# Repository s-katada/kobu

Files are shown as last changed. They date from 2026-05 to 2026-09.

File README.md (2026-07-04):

# kobu

自作分割キーボード「kobu」のモノレポです。世代ごとにディレクトリを分けています。

## ディレクトリ構成

| ディレクトリ | 中身 |
|---|---|
| [`v1/`](v1/) | 初代 kobu — KiCad PCB / ケース / ファームウェア (RMK・ZMK) / Web キーマップエディタ。詳細は [`v1/README.md`](v1/README.md) |
| [`v2/`](v2/) | kobu v2 — ケース / RMK ファームウェア。小指キーを左右 1 個ずつ追加した第 2 世代 (kobu2, PID 0x425A)。詳細は [`v2/README.md`](v2/README.md) |

## 開発環境

Nix flake / direnv。ルートの [`flake.nix`](flake.nix) が toolchain バージョンの単一情報源で、CI も同じ devshell で走ります。使い方は [`v1/README.md`](v1/README.md#開発環境) を参照。

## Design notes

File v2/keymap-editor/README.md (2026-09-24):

# kobu2 keymap editor

kobu2（v2）のキーマップとトラックボール設定を、ブラウザから直接編集する SPA です。
実機の見た目そのままの盤面を出し、**変えたいキーをクリックして選ぶ**だけで割り当てを
変更できます。

- 公開先: `https://kobu-editor.digletts.dev/v2/`（v1 と同じ Worker の `/v2` 配下）
- 対象: **kobu2 のみ**（USB PID `0x425A` / set 2 の `0x425B`）。初代 kobu はキー配列が違うので
  [`../../v1/web/rmk-editor`](../../v1/web/rmk-editor) を使ってください。
- 必要環境: WebHID が使えるデスクトップブラウザ（Chrome / Edge など Chromium 系）

kobu2 実機

## できること

| 機能 | 内容 |
|---|---|
| キーマップ編集 | 7 レイヤー × 40 キー。盤面のキーをクリック → 検索・カテゴリ・実キー入力から選択 |
| 動作の装飾 | 修飾つき (WM) / 長押しで修飾 (MT) / 長押しでレイヤー (LT) / レイヤー操作 (MO・TG・TO・OSL・DF) |
| チューニング | カーソル速度 (CPI 倍率)、スクロール間隔・反転、ステータス LED のしきい値。**その場で実機に反映** |
| バッテリー表示 | 左右それぞれの残量（30 秒ごとに自動更新） |
| 通電テスト | 全 40 キーを 1 つずつ押して、スイッチが MCU まで届いているか確かめます（組み立て後の導通確認） |
| デモ表示 | 実機が無くても盤面と操作感を確認できます |

キーマップの変更はいったん手元に溜まり、**「キーボードに書き込む」** で一括送信します。
ロック解除の操作は要りません — Vial の作法では書き込み前に解除しますが、rmk 0.8.2 が
ロックでゲートしているのは通電テストが読む `SwitchMatrixState` の 1 箇所だけで
（`host/via/mod.rs:140`、クレート中で `is_unlocked()` を参照している唯一の場所）、
`DynamicKeymapSetKeyCode` は素通りします。

### 通電テスト

「通電テスト」タブは、**キーマップを通す前のスイッチの状態**を実機から読み出します。押した
キーが緑になり、最後まで緑にならないキーはスイッチ・ソケット・FFC・XIAO のピンのどこかで
導通していません（キーマップの問題ではありません）。列や行がまとまって残った場合はその旨を
表示するので、当たりを付けてテスターを当てられます。

読んでいるのは Via の `GetKeyboardValue / SwitchMatrixState (0x02 / 0x03)` で、ファームウェア
側は `matrix_state`（rmk がキーマップ参照より前に更新するビットマップ）をそのまま返します。
つまり**レイヤーキーや割り当ての無いキーも反応します**。実装は `src/protocol/matrix.ts` と
`src/state/matrixTest.ts`。

知っておくべき挙動が 3 つあります。

* **開始時に一度ロック解除が必要です。** ファームウェアはロック中だとビットマップを書かず、
  「どのキーも押されていない」と区別の付かない返事（要求のエコー＝全ゼロ）を返します。そのため
  開始ボタンを押すと解除操作（左右いちばん外側の小指キー 2 つを同時押し）を求めます。解除状態は
  電源を入れ直すまで続きます。解除キーは左右に 1 つずつなので、**右半分の電源が入っていないと
  解除自体ができません**。
  ⚠ この 2 バイト目の極性は間違えても静かに壊れます（ロック中の 0 を「解除済み」と読むと、
  チョードを要求しないまま全ゼロを読み続け、「入力はできるのに 1 つも反応しない」画面になる）。
  `src/protocol/unlock.test.ts` がファーム側の実装と突き合わせて固定しています。
* **右半分は左半分と BLE でつながっている必要があります。** ビットマップはセントラル（左）
  にあり、右のキーはペリフェラルが転送したイベントで更新されます。右の電源スイッチが
  入っていないと、右のキーは 1 つも反応しません。
* **テスト中の打鍵はページ側で握り潰します**（Esc で終了）。ただしブラウザ自体のショート
  カット（⌘W など）は JavaScript からは止められません。

ファームウェアの変更は不要です。この機能が使う `vial_lock` は rmk の既定 feature で、
`v2/firmware/rmk/Cargo.toml` はそれを無効にしていないため、現行の UF2 がそのまま応答します。

## 開発

Node / pnpm はリポジトリルートの flake が固定しています。

```sh
cd v2/keymap-editor         # direnv がルートの devshell (Node + pnpm) を起動
pnpm install
pnpm dev                    # http://localhost:5173
pnpm test                   # vitest
pnpm lint                   # biome
pnpm typecheck
pnpm build                  # dist/
```

デプロイ用のビルドだけ `--base=/v2/` を付けます（`.github/workflows/web.yml` 参照）。
ローカルの `pnpm dev` / `pnpm build` は `/` のままです。

## 構成

| ディレクトリ | 中身 |
|---|---|
| `src/transport/` | WebHID による Vial パケット送受信。v1 エディタから流用（PID だけ kobu2 に限定） |
| `src/protocol/` | Via / Vial コマンド、ハンドシェイク、キーマップ、キーコード辞書、Custom Value。v1 から流用（`matrix.ts` だけ v2 で追加） |
| `src/board/` | **v2 固有**。実基板 CAD から起こしたジオメトリと、盤面 SVG |
| `src/state/` | zustand ストア（接続 / キーマップ / チューニング / 通電テスト） |
| `src/components/` | UI |

### 盤面ジオメトリについて

`src/board/geometry.ts` は**すべて実測値**で、目分量で描いた形は入っていません。

| 要素 | 出所 |
|---|---|
| スイッチ位置・回転 | `v2/pcb/left-main`, `v2/pcb/thumb-left` の KiCad |
| ケース外形（メイン / 親指） | `v2/case/{main,thumb}-top-plate.stl` を z=0.5 でスライス |
| トラックボール筐体・XIAO 蓋・ヒンジ | `v2/case/*.stl` の実寸 |
| キーキャップの大きさ | 実機写真（プレートの 14mm 開口を定規に実測） |

v2 の基板はスイッチが **B.Cu 側**にあるため、KiCad の標準表示は物理的な上面視と左右反転して
います（コード内に変換式を記載）。

ケース部品は**平行移動だけ**でこの座標系に乗り、しかも位置合わせは推定ではなく**証明済み**です。
印刷されたトッププレートをスライスするとスイッチごとに 14.00×14.00mm の開口が現れ、その中心
20 個すべてが KiCad のスイッチ中心と **0.00mm で一致**します。トラックボール筐体も整合しており、
中心は PMW3610 のパッドから 0.3mm しかずれません。

**唯一の推定値**がメインユニットと親指ユニットの相対位置です。両者は別 KiCad プロジェクトで
原点が無関係なため、ここだけ上の実機写真に合わせ込んでいます（誤差 2mm 程度）。
右半分は左半分の剛体鏡像として生成しています。

プレート外形にはネジ座の逃げ（縁に食い込んだ浅い円弧）が入っていますが、組み上げた状態では
その外側をサイドプレートが通るため見えません。そこで**円弧状の小さな凹みだけ**を埋めています
（4 セグメント以上・9mm 未満・18mm² 未満）。実際の段差は 2〜3 本の直線なので、大きさではなく
形で区別され、列スタッガーは残ります。

この位置合わせが将来ずれないよう、3 つのテストで固定してあります。①全キーがキャップ四隅まで
プレート多角形の内側にあること ②メインプレートが最外キャップから四辺すべて 3.15mm の余白を
持つこと（1mm ずれると余白が揃わなくなる） ③親指プレートの後端が最外キーの中心から
12.65mm 後ろにあること。

### チューニング値の永続性

チューニングの各項目は Via Custom Channel `0xC0` 経由でファームの atomic を直接書き換えます。
**ファームは保存しないため、電源を入れ直すと既定値に戻ります**
（`v2/firmware/rmk/src/config.rs` の "Persistence" を参照）。恒久的に変えたい場合は
`keyboard.toml` を編集して焼き直してください。

また 7 項目のうち「縦スクロール反転」と「LED 紫の保持時間」は、現在のファームに読み取り側が
無いため動作に影響しません。UI 上でも無効表示にしてあります。

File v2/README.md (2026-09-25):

# kobu v2

自作分割キーボード kobu の第 2 世代。v1 との**ハード面の違いは小指列最下段のキーを左右 1 個ずつ追加**したことだけです（19 → 20 キー/半分、計 40 キー）。

初代の PCB / ケース / ファームウェア / Web エディタは [`../v1/`](../v1/) にあります。

## ディレクトリ構成

| ディレクトリ | 中身 |
|---|---|
| [`case/`](case/) | ケースの STL |
| [`pcb/`](pcb/) | KiCad プロジェクト (`left-main` / `right-main` / `thumb-left` / `thumb-right`) |
| [`firmware/rmk/`](firmware/rmk/) | RMK ベースのファームウェア (Rust, thumbv7em-none-eabihf)。v1 の `firmware/rmk` からのフォーク。**クラシック構成（左手=セントラル）** |
| [`firmware/dongle/`](firmware/dongle/) | **Prospector ドングル構成**（ドングル=セントラル+ST7789 画面、左右両手=ペリフェラル）。keymap/behavior は `firmware/rmk/keyboard.toml` と要同期 |
| [`keymap-editor/`](keymap-editor/) | kobu2 専用の Web キーマップエディタ（実機の盤面をクリックして編集 + トラックボール調整）。どちらの構成でも無改修で動く（VID/PID・Via 0xC0 セマンティクス共通）|

## キーマップ

keymap

8 レイヤー構成です: **Mac**（デフォルト）/ **Win** / **Linux**（Mac ベース + Ctrl+H → Backspace のみ）/ **数字**（記号・矢印）/ **設定**（BLE プロファイル・F キー・メディア・レイヤー切替）/ **マウス**（トラックボール操作で自動起動）/ **Emacs** / **Neovim**。`▽` は下位レイヤーへの透過。最下行はマトリクス row 3 の実配置どおり「小指最下段キー + 親指クラスタ 4 キー」を 1 行に詰めて描いています。

盤面をまたぐ丸印は同時押し（コンボ）。コンボの出力は素のキーコードなので、Shift はホスト側で自然に効きます（`\` + Shift = `|`、`-` + Shift = `_` …）。

図の元データは [`firmware/rmk/keymap/kobu.yaml`](firmware/rmk/keymap/kobu.yaml) です。`keyboard.toml` とは**自動同期されない**ので、キーマップを変えたら yaml も手で直して描き直してください（devshell が stdout にバナーを出すため `<svg` 以降だけを取ります）:

```sh
cd firmware/rmk/keymap
nix develop ../../../..#firmware --command keymap draw kobu.yaml \
  | sed -n '/^<svg /,$p' > kobu.svg
```

## v1 とのファームウェア差分

- 追加キーは各半分の空いていたマトリクス交点 **ROW3×COL4**（小指列ネット × 親指行ネット）に配線。GPIO 追加なし・マトリクス寸法 (4×10) 変更なしで、keymap 座標では v1 で phantom だった **(3,0) / (3,9)** に載ります。レイヤー 0 の割り当ては左=Mission Control（Consumer 0x29F、Apple キーボードの F3 と同じ usage。2026-08-29 に LShift から変更）/ 右=RShift（他レイヤーは透過）。
  - 実基板で確認済み: 4 基板とも J1 は `1..4=/ROW0../ROW3`, `5..9=/COL0../COL4`, `10=NC` の**同一ピン配置**で、追加キーは各メイン基板の `SW16 = /ROW3 × /COL4`（小指列の最下段、既存最下行の 16mm 下）。/ROW3 が FFC pin4 でメインユニットへ届いています。
  - ⚠️ FFC ケーブルは v1 と逆で**ストレート結線（pin N ↔ pin N）**が必要です。v2 の FFC には電源線が無く（pin10 = NC、メイン基板はスイッチとダイオードのみの完全パッシブ）、誤ったケーブルでも MCU ピンが電源に張り付くことはありませんが、マトリクスは全く読めません。導通チェック手順は `firmware/rmk/keyboard.toml` 冒頭コメント参照。
- 識別子: name/product_name = **kobu2**、product_id = **0x425A**（VID `0x4b4f` と Vial keyboard UID は v1 と共通）。[web editor](../v1/web/rmk-editor/) は v1/v2 両方の PID を受け付けます。2 台目セットは `--features set-2` で **kobu2 squid / 0x425B**（後述）。
- それ以外（build.rs のレジストリパッチ、`src/`、メモリレイアウト、依存クレートのバージョン）は v1 と同一です。
  - うち 3 つは [`firmware/dongle/`](firmware/dongle/) のための 2026-08 追加: `patch_rmk_peripheral_manager_source_disambiguation`（**id≠0 のときだけ発火** → ペリフェラルが id0 の右手のみのクラシック構成では実行時に不活性）、`patch_rmk_split_connect_timeout_widen`（split 接続タイムアウト 5s→12s。クラシック構成では SCANNING_MUTEX が無競合でタイムアウト自体ほぼ発火しないため実質不可視）、`patch_rmk_split_adv_set_token`（広告のセット識別トークン。クラシック構成は `src/set_token.rs` で set 1=`0x41` / set 2=`0x42` を起動時に載せ、2 台同時通電でも左右が誤ペアしない。ドングルの `0x4B` とは別レンジ）。

## ⚠️ build.rs は v1 と同一内容に保つ

v1/v2 の build.rs はどちらも**共有 cargo registry のソースを in-place パッチ**します。両者が同一内容ならパッチは冪等で、どちらのツリーを先にビルドしても安全です。**片方だけにパッチを足して乖離させた場合**は、もう片方をビルドする前に

```sh
cargo clean --release -p rmk -p trouble-host -p rmk-macro
```

で 3 crate をパッチ済みソースから作り直してください（CI はジョブごとに pristine な registry なので無関係）。

## ビルド

v1 と同じで、リポジトリルートの devshell を使います:

```sh
cd v2/firmware/rmk        # direnv が firmware devshell を自動起動
cargo build --release --bin central
cargo build --release --bin peripheral
```

UF2 は CI が [firmware-latest リリース](../../releases/tag/firmware-latest)に `kobu2-rmk-central.uf2` / `kobu2-rmk-peripheral.uf2`（+ `-reset` 版）として公開します。ローカルで作る場合は devshell の `kobu-uf2conv`:

```sh
kobu-uf2conv target/thumbv7em-none-eabihf/release/central    kobu2-rmk-central.uf2
kobu-uf2conv target/thumbv7em-none-eabihf/release/peripheral kobu2-rmk-peripheral.uf2
```

### USB で central に焼く（キーマップ反映）

左手をデータ対応 USB で繋いだ状態で、firmware devshell から:

```sh
# clearlayout → 通常（保存キーマップを keyboard.toml で書き直し。BLE ボンドは残る）
v2/scripts/kobu-flash-central

# キーマップ以外の変更だけなら clearlayout なし
v2/scripts/kobu-flash-central --plain

# BLE のみのときに USB を挿すまで待ってから焼く
v2/scripts/kobu-flash-central --plain --wait
```

UF2 だけ渡す低レベル版は [`scripts/kobu-flash`](scripts/kobu-flash) です。

## 2 台の kobu2 を同時に使う（セット識別）

クラシック構成はデフォルトで **set 1**（split 広告トークン `0x41`、Mac 上の名前 `kobu2 octopus`、PID `0x425A`）です。2 台目は **同じ左右ペアごと**に `--features set-2` でビルドした UF2 を焼きます（トークン `0x42`、名前 `kobu2 squid`、PID `0x425B`）。トークンが違うと左右の初回ペアリングが相手セットに掴まれません。Mac 上も別名になるのでプロファイルを取り違えにくくなります。

```sh
# 2 台目セット（左右とも同じ feature）
cargo build --release --features set-2 --bin central
cargo build --release --features set-2 --bin peripheral
kobu-uf2conv target/thumbv7em-none-eabihf/release/central    kobu2-rmk-central-set2.uf2
kobu-uf2conv target/thumbv7em-none-eabihf/release/peripheral kobu2-rmk-peripheral-set2.uf2
```

**初回だけ** 各半分を `clear_storage=true` ビルド（または nuke）でボンドを消してから通常 UF2 を焼き、**1 セットずつ電源を入れて**左右を組み直してください。トークン付き広告は旧ファーム（token 0）とも相互に不可視なので、片側だけ古い UF2 のままだと繋がりません。

## XIAO の完全消去（flash nuke）

`kobu2-rmk-*-reset.uf2`（`clear_layout` ビルド）は保存済みキーマップを消すだけで、アプリ本体や BLE ボンドはそのまま残ります。XIAO を**本当にまっさら**（アプリなし・ブートローダのみ）に戻したいときは [`scripts/xiao-nuke.uf2`](scripts/xiao-nuke.uf2) を焼きます。RESET 2 連打 → ドラッグ & ドロップでも、[`scripts/kobu-flash`](scripts/kobu-flash) でも書き込めます:

```sh
# まっさらにするだけ
scripts/kobu-flash scripts/xiao-nuke.uf2

# まっさらにしてからクリーンインストール（nuke 後は自動でブートローダに
# 留まるので、そのまま続けて焼ける）
scripts/kobu-flash scripts/xiao-nuke.uf2 firmware/rmk/kobu2-rmk-central.uf2
```

- 消去範囲は **0x1000–0xC0000**: アプリ + RMK storage（0xA0000–0xC0000 のキーマップ・BLE ボンド・Vial 状態）で、ファームウェアが書き込む領域のすべて。MBR（0x0–0x1000）と Adafruit UF2 ブートローダ（0xF4000–）には触れません。終端を 0xC0000 で止めるのは、出荷版ブートローダ (0.6.1) の UF2 書き込みウィンドウが実測 0x1000–0xEA000 で、ウィンドウ外のブロックは受領カウントされず「全ブロック受領 → 自動リセット」が発火しなくなるため（0xF4000 終端で実害を確認済み。フラッシュ自体は書けるが物理 RESET が必要になる）。なお過去に ZMK を焼いた個体の settings（0xEA000 以降）は UF2 経由では消せないので、必要なら SWD で。
- 実行コードを含まない「全ブロック 0xFF のデータだけ」の UF2 で、ページ消去はブートローダの書き込みパスが行います。書き込み後は先頭ワードが 0xFFFFFFFF（= 有効なアプリなし）になるため、XIAO は再起動後も自動でブートローダ（XIAO-SENSE ドライブ）に留まり、そのまま次の UF2 を受け付けます。
- nRF52840 + Adafruit UF2 ブートローダの組み合わせなら v1 の XIAO にもそのまま使えます。
- キーボード側のボンドは消えますが、**ホスト側（macOS 等）の Bluetooth 設定に残った古いペアリングは別途削除**してください。

再生成は [`scripts/gen-xiao-nuke`](scripts/gen-xiao-nuke)（Python 3 標準ライブラリのみ、出力はバイト単位で再現可能）。CI も再生成してコミット済みファイルと一致することを検証します。

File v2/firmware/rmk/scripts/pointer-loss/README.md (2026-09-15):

# pointer-loss — Mac 側から右ボールのサンプル欠落を測る

kobu2 が BLE で送ってくるマウスレポートを Mac 側で受け身に記録し、
「速く動かしている最中に、ホスト接続イベント（15ms）にレポートが乗らなかった割合」と
「欠けた分の移動量が次のレポートに繰り越されているか（保存比）」を数値化します。
2026-09-08 の計測では速い移動中の約 12% のイベントでレポートが欠け、保存比が 1.0
（＝欠けた移動量は消失）だったことが「もっさり＝アンダートラベル」の直接証拠になりました。

キーボードの usage page (0x07) は記録しません（キー入力は残らない）。

## 使い方

```sh
# 1. ビルド（nix devshell の SDK と衝突するので、システム SDK を明示）
cd v2/firmware/rmk/scripts/pointer-loss
env -u SDKROOT -u DEVELOPER_DIR SDKROOT=/Library/Developer/CommandLineTools/SDKs/MacOSX.sdk \
  /usr/bin/swiftc -O hidlog.swift -o hidlog

# 2. 記録（数分〜、右ボールを普段どおり動かす。Ctrl-C で終了）
./hidlog > hid_log.txt
#    先頭行 "# open result: 0x00000000" 以外（0xe00002e2 = 入力監視の許可なし）なら
#    システム設定 > プライバシーとセキュリティ > 入力監視 でターミナルを許可して再実行。

# 3. 集計
python3 analyze.py hid_log.txt
```

## 見るべき数値

- `P(no report at a connection event)`: 速い移動中の欠落率。修正後は 0.12 → 0.0x を期待。
- `CONSERVATION ... gap=2 events`: 30ms ギャップ後のレポートの移動量比。**1.0 なら移動量が消えている**、
  2.0 なら遅れて届いているだけ（カーソルは狙った場所に着く）。
- `TIMELINE`: 1 分ごとの欠落率。時間とともに悪化するか、うねりがあるかを見る。
- `WHEEL/PAN`: 左ボール（中央ローカル、スプリット経路なし）との比較用。

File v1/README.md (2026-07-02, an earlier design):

# kobu v1

自作分割キーボード「kobitokey」にインスパイアされて作った派生キーボード「kobu」(初代) の KiCad プロジェクトとファームウェアです。親指キーを追加し、メインキー側を 2 キー削っています。

## ディレクトリ構成

| ディレクトリ | 中身 |
|---|---|
| [`pcb/`](pcb/) | KiCad プロジェクト (PCB / 回路図) |
| [`case/`](case/) | ケースの STEP / STL |
| [`firmware/rmk/`](firmware/rmk/) | RMK ベースのファームウェア (Rust, thumbv7em-none-eabihf) |
| [`firmware/zmk/`](firmware/zmk/) | ZMK 版ファームウェア (Zephyr, Nix/flake ビルド) |
| [`web/rmk-editor/`](web/rmk-editor/) | RMK 用 Web キーマップエディタ (WebHID + Vial protocol, React) |
| [`web/zmk-editor/`](web/zmk-editor/) | ZMK 用 Web キーマップエディタ (ZMK Studio over USB/BLE, React) |

## 開発環境

リポジトリルート (`../flake.nix`) が toolchain バージョンの単一情報源。CI も同じ devshell で走るので host とドリフトしない。

### direnv ですぐに使う (推奨)

[nix-direnv](https://github.com/nix-community/nix-direnv) を入れていれば `cd` するだけで対応する devshell が自動起動する:

```sh
direnv allow                 # 初回のみ (リポジトリルートで)
cd ~/git/private/kobu        # → 全部入り devshell (firmware + web)
cd v1/firmware/rmk/          # → firmware-only (Rust + flip-link + probe-rs)
cd v1/web/rmk-editor/        # → web-only      (Node 26 + pnpm; v1/web/zmk-editor も同じ)
```

各ディレクトリの `.envrc` がルートの `flake.nix` の対応する `devShells.*` を `use flake` で読み込む構成。

### 手動で起動する場合 (リポジトリルートで)

```sh
nix develop               # 全部入り
nix develop .#firmware    # firmware のみ
nix develop .#web         # web のみ
```

## 主要部品

- スイッチ: Kailh Choc V2 ホットスワップ（1.00u）
- ダイオード: SOD-123
- コネクタ: Hirose FH12-10S-0.5SH（FFC/FPC 10 ピン, 0.5mm ピッチ）
- MCU: Seeed XIAO nRF52840 BLE（左右親指ユニットに 1 個ずつ）
- トラックボール: PMW3610 光学センサー（左右親指ユニットに 1 個ずつ、3 線 SPI）

## キーマップ

keymap

## Vial でキーマップを編集する

ブラウザから kobu のキーマップ・マクロ・コンボを動的に編集できます。RMK が公式に提供しているオンライン編集ルートは Vial 互換のみで、**ブラウザ (vial.rocks) からは USB Raw HID 経由**でしか繋がりません。日常的に BLE で使っていても、編集時だけ USB ケーブルを挿す必要があります。

> **補足**: RMK 0.8 のファームウェア自体は BLE でも Vial プロトコルを喋れます ([`BleVialServer`](https://github.com/HaoboGu/rmk/blob/main/rmk/src/ble/host_service/vial.rs) として実装済み)。ただし Web Bluetooth は HID service UUID `0x1812` をブロックリストで除外しているため vial.rocks からは届きません。Linux/Windows の **Vial デスクトップアプリ** であれば BLE 経由で接続できる可能性がありますが、kobu 上での動作確認はまだ取れていません。

### 必要なもの

- データ通信対応の USB-C ケーブル
- Chromium 系ブラウザ（Chrome / Edge / Brave）。WebHID を使うので Safari と Firefox は不可
- central（左半分）に書き込んだ最新ファームウェア

### 接続手順

1. central を USB ケーブルで PC に接続する（peripheral は接続不要 / 接続しても無視される）
2. <https://vial.rocks> を開く
3. "Authorize device" ボタンを押し、ポップアップで `kobu` を選択
4. キーマップ編集タブで変更したいキーをクリック → 新しいキーコードを選択 → 自動保存

### Unlock chord

キーマップ変更を許可するには、物理位置 `(0, 0)` と `(0, 9)` を**同時押し**します。`(row, col)` は `keyboard.toml` の matrix 上の位置で、論理キーコードではありません。kobu の場合これは:

- `(0, 0)` = 左半分 **外側 pinky**（物理 Q キー位置）
- `(0, 9)` = 右半分 **外側 pinky**（物理 P キー位置）

両手の外側 pinky を同時に押す動作は通常のタイピングではまず起きないので、誤操作で Vial が unlock されることはありません。Vial で Q や P のキーコードを別物に置き換えても、unlock chord は matrix 位置で決まっているため変化しません。

### Layer 3 = Bluetooth 操作レイヤー

Layer 3 row 0 には RMK の "user keycode" 経由で BLE 操作系を割り当てています。Vial 上では `customKeycodes` で定義したラベルで表示されます。

| Vial 上のラベル | 内部の user keycode | 動作 |
|---|---|---|
| BT0 | User0 | BLE プロファイル 0 に切り替え |
| BT1 | User1 | BLE プロファイル 1 に切り替え |
| BT2 | User2 | BLE プロファイル 2 に切り替え |
| BT3 | User3 | BLE プロファイル 3 に切り替え |
| Next BT | User4 | 次のプロファイルに切り替え |
| Prev BT | User5 | 前のプロファイルに切り替え |
| Clear BT | User6 | 現在のプロファイルのペアリング情報を消去 |
| Switch Output | User7 | デフォルト出力先を USB / BLE で切り替え |

ラベルと内部 keycode の対応は `ble_profiles_num = 4` に依存します。`keyboard.toml` の `[rmk]` でこの値を変えた場合、`vial.json` 側の `customKeycodes` も同じ並び規則で書き直す必要があります（RMK 0.8 の `src/keyboard.rs::process_user` 参照）。

数字レイヤー（Layer 2）は**右親指・XIAO 直下から 1 つ外**の `LT(2, Space)`（Space タップ / ホールドで Layer 2）、設定レイヤー（Layer 3）は**さらに 1 つ外**の `LT(3, Enter)`（Enter タップ / ホールドで Layer 3）で入ります。Emacs レイヤー（Layer 5）は Win/Linux モード（Layer 1）でのみ、左親指・XIAO 直下から 1 つ外の `LT(5, LGui)` で入ります。

キーマップは [KobitoKey_QWERTY](https://github.com/s-katada/KobitoKey_QWERTY)（ZMK）から 1:1 で移植しています。kobu の親指 PCB は KobitoKey の 3 親指 / 側に対して 4 親指 / 側あるので、KobitoKey にない一番外側の親指 1 個ずつには Backspace を割り当てています。

| 位置（XIAO 直下 → 外側） | 左手親指 | 右手親指 |
|---|---|---|
| XIAO 直下（内側 SW2） | **英数**（Shift ホールド） | **Esc**（Alt ホールド） |
| SW3 | Ctrl | **Space**（数字層ホールド） |
| SW4 | Backspace（Cmd ホールド） | **Enter**（設定層ホールド） |
| 外側 SW5（kobu 拡張） | Backspace | Backspace |

### macOS で電池残量を表示する

central（左半分）は XIAO nRF52840 BLE の内蔵 1MΩ / 510kΩ 電圧分圧 (ratio = 510/1510 ≒ 0.338) から BAT 電圧を ADC（P0_31）で読み取り、標準 BLE Battery Service (UUID `0x180F`) として host に通知します。macOS の Bluetooth メニュー / システム設定では、Apple Magic Keyboard と同じ位置にバッテリー残量がパーセントで表示されます。

最新ファームウェアを central にフラッシュ済みなのに残量が出ない場合は、**ペアリング情報を作り直す**必要があります。古い build で BLE 接続したことがある macOS は、その時点の GATT サービス構成（Battery Service が含まれていない世代）をキャッシュしているため、ファームを更新しただけでは新しい characteristic を読み直しに来ません。

1. システム設定 → Bluetooth で `kobu` の (i) → "このデバイスの登録を解除"
2. central の電源を入れ直す（USB を一度抜き差しするか、左親指の電源スライドスイッチで OFF→ON）
3. macOS が `kobu` を再発見したら接続
4. Bluetooth メニューを開くと残量が表示される

LED が緑＝60% 以上 / 黄＝20〜60% / 赤＝20% 以下を示します（USB 給電中は赤が抑制されて緑に倒れる）。BLE の数値表示は LED と独立した経路で、`firmware/rmk/keyboard.toml` の `[ble]` セクションで `battery_adc_pin = "P0_31"` と分圧比 (`adc_divider_measured = 510`, `adc_divider_total = 1510`) を設定しています。XIAO nRF52840 BLE の BAT 分圧は対称な 1M/1M ではなく **R10 = 1MΩ / R11 = 510kΩ の非対称** で、`ratio = R11 / (R10 + R11) = 0.338` です。1/2 にしてしまうと健全な 4.0V LiPo が 2.7V と decode され、`get_battery_percent` が 0% を返してしまうので注意。

### 工場リセット

書き換えたキーマップを丸ごと捨ててビルド時の keymap に戻したいときは:

1. `firmware/rmk/keyboard.toml` の `[storage]` で `clear_layout = true` に変更
2. central をフラッシュ
3. 起動後に `clear_layout = false` に戻し、再度フラッシュ

BLE ペアリング情報も含めて全部消したいときは `clear_storage = true` を使います。

### 既知の制約

- **vial.rocks (Web Bluetooth) からは BLE 経由で繋げない**。HID service が Web Bluetooth のブロックリストにあるため。ブラウザ編集は USB ケーブル必須。
- **Vial デスクトップアプリ + BLE での編集は未検証**。RMK 0.8 の `BleVialServer` は実装されているので Linux/Windows の Vial 経由なら届く可能性あり。動いた人がいたら issue 起票歓迎。
- **peripheral 側（右半分）は USB に挿しても Vial で認識されない**。Vial 通信は central だけが処理します。
- 完全な Web 経由 (Web Bluetooth or WebUSB) 編集は RMK upstream の独自プロトコル ([HaoboGu/rmk#558](https://github.com/HaoboGu/rmk/issues/558)) 完成待ち。

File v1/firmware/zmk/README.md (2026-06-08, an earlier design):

# kobu — ZMK firmware

A ZMK port of kobu's firmware. The original RMK firmware is preserved in
[`../rmk/`](../rmk) (`firmware/rmk/`); this directory is the ZMK config. The
build is driven by the single repo-root [`flake.nix`](../../flake.nix) (via
`zmk-nix`), so **no west / Zephyr / SDK install is required**. `cd`-ing here
activates the `zmk` dev shell through [`.envrc`](.envrc).

The keymap, trackball behavior, BLE tuning and RGB-LED status are ported 1:1
from the RMK firmware (`../rmk/keyboard.toml`, `../rmk/src/*.rs`), which itself derives
from [KobitoKey_QWERTY](https://github.com/s-katada/KobitoKey_QWERTY) (ZMK).
kobu is a different PCB, so the matrix pins, the `row2col` diode direction and
the dual-trackball wiring are kobu-specific (see `config/boards/shields/kobu/`).

## Layout

```
firmware/zmk/
  .envrc                          # `use flake "path:../..#zmk"` (build shell)
  build.yaml                      # GitHub Actions matrix (CI parity; not used by Nix)
  config/
    west.yml                      # pins ZMK v0.3 + PMW3610 driver + rgbled-widget
    kobu.keymap                   # 7 layers, combos, behaviors (1:1 from RMK)
    boards/shields/kobu/
      kobu.dtsi                   # 4x10 matrix (row2col), split inputs, layout
      kobu_left.overlay           # central: SPI + left ball (scroll) + auto-mouse
      kobu_right.overlay          # peripheral: col override + right ball (pointer)
      kobu_left.conf / kobu_right.conf
      Kconfig.shield / Kconfig.defconfig
      kobu.zmk.yml
```

LEFT = central (local trackball → scroll). RIGHT = peripheral (trackball
forwarded over the split link → pointer + auto-mouse layer 4).

## Build (Nix)

The ZMK build is exposed by the repo-root flake (`packages.zmk*`), with
`zephyrDepsHash` already pinned, so a clean build just works (verified building
both halves + the reset image). Run from the **repo root**:

```sh
# Both halves + reset, named for kobu -> result/kobu-zmk-{left,right,reset}.uf2
nix build .#zmk-bundle
cp -L result/kobu-zmk-left.uf2  ./kobu-zmk-left.uf2
cp -L result/kobu-zmk-right.uf2 ./kobu-zmk-right.uf2
cp -L result/kobu-zmk-reset.uf2 ./kobu-zmk-reset.uf2

# Or just the two halves:  nix build .#zmk   -> result/zmk_{left,right}.uf2
# Or just the reset image: nix build .#zmk-reset
```

> Files must be tracked by git for the flake to see them (`git add firmware/zmk`).

If `firmware/zmk/config/west.yml` ever changes (ZMK / module revisions),
re-bootstrap the hash: set `zmkDepsHash = lib.fakeHash;` in the root `flake.nix`,
run `nix build .#zmk`, and paste the reported `got: sha256-...` back in.

## Flash

Double-tap the XIAO reset button; it mounts as a USB mass-storage volume. Copy
the matching UF2 onto it:

```sh
cp kobu-zmk-left.uf2  /Volumes/XIAO-SENSE/     # central / left half
cp kobu-zmk-right.uf2 /Volumes/XIAO-SENSE/     # peripheral / right half
```

`kobu-zmk-reset.uf2` clears BLE bonds + stored settings (flash it, then reflash
the normal half firmware).

## Fallback: manual west build

If you prefer raw west, the root flake's `zmk` dev shell provides the full
toolchain (auto-activated here via `.envrc`, or `nix develop .#zmk` from the
repo root):

```sh
cd firmware/zmk          # .envrc activates the zmk shell (or: nix develop ../..#zmk)
west init -l config
west update
west build -p -d build/left  -s zmk/app -b seeeduino_xiao_ble \
  -S studio-rpc-usb-uart \
  -- -DSHIELD="kobu_left rgbled_adapter" -DZMK_CONFIG="$PWD/config" -DZMK_EXTRA_MODULES="$PWD/config"
west build -p -d build/right -s zmk/app -b seeeduino_xiao_ble \
  -- -DSHIELD="kobu_right rgbled_adapter" -DZMK_CONFIG="$PWD/config" -DZMK_EXTRA_MODULES="$PWD/config"
cp -L build/left/zephyr/zmk.uf2  ../../kobu-zmk-left.uf2
cp -L build/right/zephyr/zmk.uf2 ../../kobu-zmk-right.uf2
```

## Keymap editing

ZMK Studio (over USB, central only) replaces kobu's RMK Vial/web editor.
`CONFIG_ZMK_STUDIO=y` is set on the central; connect at <https://zmk.studio>.

## Differences from the RMK firmware (faithful-port notes)

- Trackball **direction flags** (scroll roll-right = up; pointer Y-invert)
  depend on physical ball mounting — RMK exposes them as runtime flags. The ZMK
  defaults here match RMK's defaults; if scroll/pointer goes the wrong way on
  the bench, flip `INPUT_TRANSFORM_*` in the overlays (see comments).
- The RMK auto-mouse "travel gate" / sub-count keepalive are approximated by
  ZMK's `zip_temp_layer` (activate on motion after 300 ms prior-idle, 150 ms
  idle-deactivate); behavior is equivalent for normal use.
- RGB LED uses `zmk-rgbled-widget` (battery boot color + per-layer colors +
  connection status) instead of RMK's bespoke controller; layer colors match
  `../rmk/src/status_led.rs`.

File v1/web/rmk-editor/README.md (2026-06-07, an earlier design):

# kobu-editor (web app)

Web-based keymap editor for the [kobu](../) split keyboard, served as a
single-page app. Talks to kobu's central half over USB or BLE-HoG via
the WebHID API and the Vial wire protocol — no native install, no
driver required.

Lives inside the kobu monorepo. Firmware at [`../firmware/`](../firmware/),
hardware at [`../pcb/`](../pcb/).

## What you can do with it

| Feature | Status |
|---|---|
| Read / write keymap (all firmware layers × 4×10 matrix; layer count read from the device) | ✅ |
| Categorised keycode picker (basic / mods / layers / mouse / media / kobu-specific BT keys) | ✅ |
| Layer 3 dedicated BLE-profile panel | ✅ |
| Macros (Vial advanced format — tap / press / release / delay) | ✅ |
| Combos (up to 4 input keys → 1 output key, ×16 slots) | ✅ |
| Tap-dance (tap / hold / double-tap / hold-after-tap + per-entry tap-term) | ✅ |
| Firmware install from latest GitHub Release (UF2 + clean install) | ✅ |
| PWA / offline support (install as an app, works without network) | ✅ |
| Unsupported-browser splash with download recommendations | ✅ |
| Trackball / scroll / LED tuning panel | 🚧 see #39, #40 |

## Browser support

WebHID is Chromium-only:

| Platform | Supported browsers |
|---|---|
| Desktop (macOS / Windows / Linux) | Chrome, Edge, Brave, Opera, Vivaldi |
| Android | Chrome (USB-OTG cable required for kobu) |
| iOS | ❌ — all iOS browsers use WebKit; no WebHID |
| Safari (any version) | ❌ |
| Firefox (any version) | ❌ |

The app detects the environment on load and shows a dedicated splash
explaining what to install if WebHID is missing.

## User guide

### First-time setup

1. Connect kobu's **central half** (left half) to your computer with a
   data-capable USB-C cable. The peripheral half does not need to be
   connected.
2. Open the kobu-editor URL in Chrome (or another Chromium browser).
3. Click **「kobu に接続」** ("Connect to kobu"). The browser pops up a
   device-picker — select kobu and click *Connect*.
4. The editor loads your current keymap from the device.

> **BLE editing works too**: once kobu is paired in your OS Bluetooth
> settings, Chrome's WebHID picker on macOS / Android / some Linux
> distros surfaces the BLE-paired kobu just like a USB device. Windows
> often requires USB because its HID stack doesn't always expose BLE
> HID devices.

### Editing keys

1. Click a key on the SVG matrix.
2. Pick a new keycode from the picker (search box + categorised tabs).
3. Click **「保存」** ("Save"). The editor will only persist if the
   firmware is **unlocked** (see below).
4. The amber dot on the layer tab fades as the firmware confirms each
   write.

### Unlocking the firmware

Vial firmwares ship locked — you have to physically hold a key
**chord** to prove you have the keyboard in front of you before
writes are accepted. For kobu the chord is the **two outermost pinky
keys** (`row 0, col 0` and `row 0, col 9` in the matrix — the Q and P
positions on a default QWERTY layout).

If you ever remap those positions to other keycodes, the chord is
still the *matrix* position, not the logical key — the unlock is
unaffected.

### Macros / combos / tap-dance

Scroll past the keymap section to find dedicated panels for each. All
three open the same keycode picker for individual fields, so the
familiar shortcuts apply.

### Firmware install

The **「ファームウェア」** section at the bottom of the page fetches
the latest UF2 from the kobu GitHub release and writes it via the
File System Access API (also Chromium-only). Two flows:

- **通常インストール** — overlay the new firmware; keeps your existing
  keymap.
- **クリーンインストール** — also resets the saved keymap to the
  firmware's build-time default. Useful when migrating between
  firmware versions that change the matrix shape.

Both flows do *not* touch BLE pairings.

## FAQ

**Q. Safari で動きません.**
A. WebHID API がないので動きません。Chromium 系（Chrome / Edge /
Brave / Opera）をインストールしてください。iOS の Chrome も実は
WebKit エンジンなので動きません — 別のデバイスを使ってください。

**Q. kobu に接続を押しても何も出てきません.**
A. データ通信非対応の USB ケーブル（充電専用ケーブル）の可能性が
あります。データ対応ケーブルに差し替えて再試行してください。

**Q. デバイスは選択できるけど "デバイスがロックされています" と出ます.**
A. 物理 unlock chord（両外側 pinky 同時押し）が必要です。`(0, 0)` と
`(0, 9)` の matrix 位置を同時に押し、押したまま「保存」してください。
詳細はリポジトリ root の [README.md](../README.md#unlock-chord) を
参照。

**Q. BLE 経由で繋がりません.**
A. macOS / Android / 一部 Linux なら、OS Bluetooth 設定で kobu を
ペアリング済みなら Chrome の WebHID ピッカーに出ます。Windows の HID
スタックは BLE HID デバイスを surface しないことが多く、その場合は
USB ケーブルで接続してください。

**Q. インストールしたのに次回も「初回ロード中」と出ます.**
A. PWA としてインストールしてもブラウザがキャッシュを別途消すと再
ロードが走ります。ホーム画面アイコンから開いてもキャッシュが消えて
いれば最初の HTML/JS フェッチだけは必要です。

**Q. 設定をやり直したい.**
A. ヘッダー右の "切断" を押し、もう一度接続すると最新の状態を読み
直します。完全に出荷状態に戻したい場合は firmware section の
"Reset" を使うか、`keyboard.toml` の `clear_layout = true` で再
フラッシュしてください（BLE ペアリングごと消すなら `clear_storage`）。

## Develop

The kobu nix devshell provides Node and pnpm — the same versions CI
uses. Enter it from the **repo root** (one level up from this
directory) or rely on direnv if you have nix-direnv installed:

```sh
nix develop                # at the kobu repo root, or
cd web && nix develop ..#web

pnpm install               # one-time
pnpm dev                   # http://localhost:5173
pnpm test                  # vitest
pnpm lint                  # biome
pnpm typecheck             # tsc -b --noEmit
pnpm build                 # production bundle in dist/
```

`flake.nix` pins Node 26 and pnpm. Bumping the Node major is a
one-line change in `../flake.nix` and CI picks it up automatically —
local dev and CI cannot drift.

### Cloudflare Workers (production hosting)

The SPA ships as a Cloudflare Worker that serves the Vite-built
`dist/` directory plus a `/__release` proxy to GitHub (so the
firmware-install flow can download UF2 binaries without CORS pain).
Locally:

```sh
pnpm cf:dev      # wrangler dev
pnpm cf:deploy   # build + wrangler deploy   (needs API token)
pnpm cf:tail     # tail production logs
```

CI deploys to production automatically on every push to `main` once
the lint / typecheck / test / build steps succeed. This requires two
**repository secrets** in GitHub:

- `CLOUDFLARE_API_TOKEN` — token scoped to *Edit Workers Scripts* +
  *Account → Workers KV Storage*.
- `CLOUDFLARE_ACCOUNT_ID` — your CF account id (visible in the
  dashboard URL).

The Worker also attaches a strict Content-Security-Policy and a
`Permissions-Policy` that grants `hid` only to our origin. The
`/__release` proxy keeps GitHub's response headers unmodified.

## Architecture (high-level)

```
        ┌────────────────────────────────────────────────────┐
  App ──┤  React 19 + Tailwind 4 + Zustand 5                 │
        │  ─────────────────────────────────────────────     │
        │  ConnectButton    KeymapView      KeycodePicker    │
        │  EditorToolbar    MacroEditor     ComboEditor      │
        │  MorseEditor      BluetoothPanel  FirmwareSection  │
        │  PwaUpdateToast   UnsupportedBrowserSplash         │
        └───────────────┬────────────────────────────────────┘
                        │
                        ▼  state/
        ┌────────────────────────────────────────────────────┐
        │  connection · editor · macros · combos · morses    │
        │  firmware                                          │
        └───────────────┬────────────────────────────────────┘
                        │
                        ▼  protocol/
        ┌────────────────────────────────────────────────────┐
        │  handshake · keymap · macros · combos · morses     │
        │  unlock · cache · commands (32-byte Vial packets)  │
        └───────────────┬────────────────────────────────────┘
                        │
                        ▼  transport/
        ┌────────────────────────────────────────────────────┐
        │  WebHidTransport (navigator.hid + ViaReport HID    │
        │                   collection 0xFF60/0x61)          │
        └────────────────────────────────────────────────────┘
                        │
                        ▼
                     ┌──────┐
                     │ kobu │  RMK 0.8 firmware
                     └──────┘
```

Decisions log: [#21](https://github.com/s-katada/kobu/issues/21).
Roadmap meta: [#41](https://github.com/s-katada/kobu/issues/41).

## Tech stack

- React 19 + TypeScript (strict, `noUncheckedIndexedAccess`,
  `exactOptionalPropertyTypes`)
- Vite 8 + Rolldown (build / dev server)
- Tailwind CSS 4 (utility styling)
- Zustand 5 (state management)
- Biome 2 (lint + format)
- Vitest 4 (unit + component tests, jsdom)
- vite-plugin-pwa + workbox (offline support)
- Cloudflare Workers + wrangler (production hosting)

## License

GPL-2.0-or-later — chosen pre-emptively to allow borrowing
protocol-layer code from upstream Vial projects. Will revisit if it
turns out we wrote the protocol layer from scratch.

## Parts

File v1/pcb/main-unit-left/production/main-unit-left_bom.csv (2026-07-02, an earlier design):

Designator | Footprint | Quantity | Value | LCSC Part #
D1, D10, D11, D12, D13, D14, D15, D2, D3, D4, D5, D6, D7, D8, D9 | D_SOD-123 | 15 | D
J1 | Hirose_FH12-10S-0.5SH_1x10-1MP_P0.50mm_Horizontal | 1 | Conn_01x10
SW1, SW10, SW11, SW12, SW13, SW14, SW15, SW2, SW3, SW4, SW5, SW6, SW7, SW8, SW9 | SW_Hotswap_Kailh_Choc_V2_1.00u | 15 | SW_Push

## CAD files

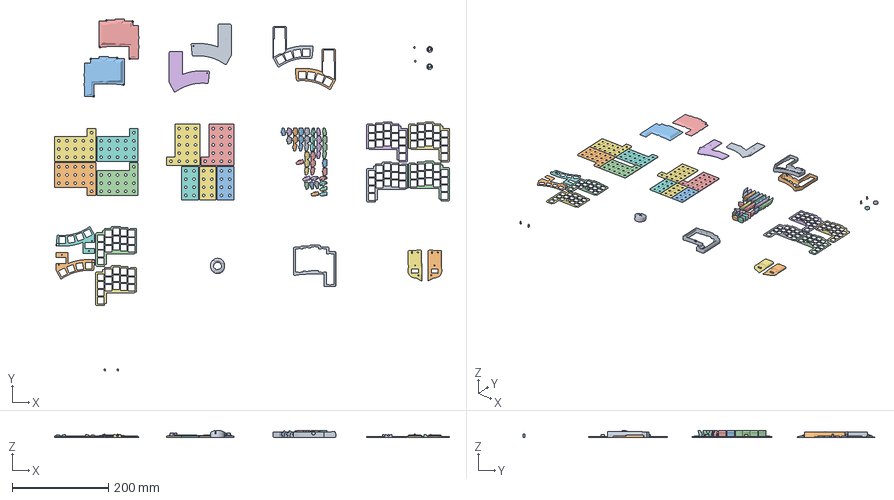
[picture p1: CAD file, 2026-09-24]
v2/case/key-tray-main.3mf
821.0 x 731.2 x 15.3 mm
main-side-plate.stl
xiao-cover-right.stl
reset-switch.stl x 4
main-bottom-plate.stl x 2
hinji-cover.stl x 2
xiao-cover-left.stl
trabo-case.stl
TypeSurfer16_4行.stl x 2
main-top-plate.stl x 6
TypeSurfer16_3行.stl x 6
thumb-side-plate.stl x 2
key-tray-main.stl x 6
TypeSurfer16_3行.stl_3 x 2
TypeSurfer16_ホーミング.stl x 2
thumb-top-plate.stl x 2
TypeSurfer16_4行.stl_2
TypeSurfer16_4行.stl_3 x 3
TypeSurfer16_3行.stl_2 x 8
thumb-bottom-plate.stl x 2
key-tray-thumb.stl x 3

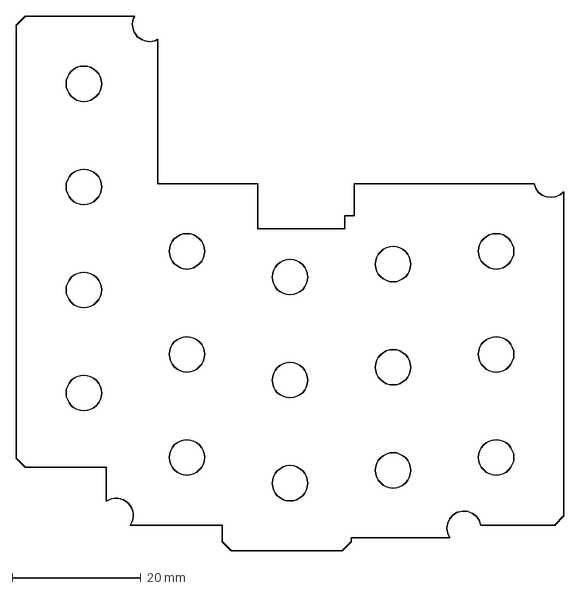
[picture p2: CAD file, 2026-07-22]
v2/pcb/main-top.dxf
85.0 x 83.0 mm

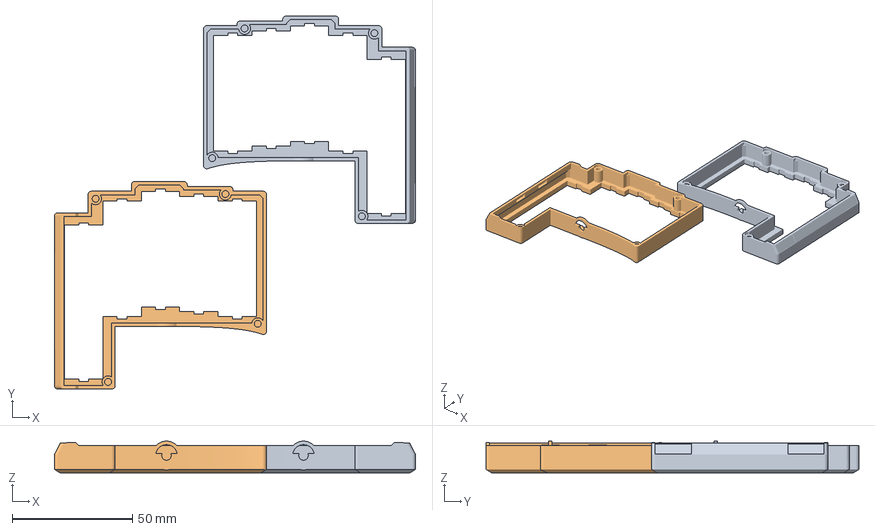
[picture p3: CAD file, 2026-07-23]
v2/case/main-side-plate.3mf
150.3 x 155.2 x 13.2 mm
main-side-plate.stl x 2

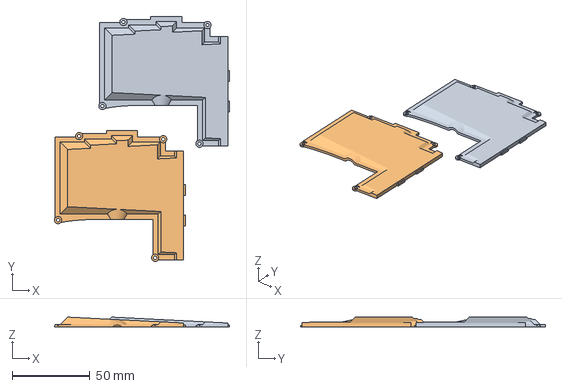
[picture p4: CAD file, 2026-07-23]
v2/case/main-bottom-plate.3mf
112.4 x 157.3 x 6.30 mm
main-bottom-plate.stl x 2

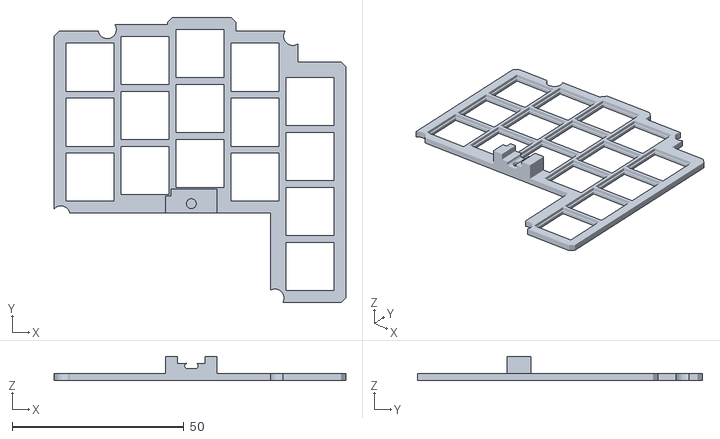
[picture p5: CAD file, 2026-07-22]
v2/case/main-top-plate.stl
85.0 x 83.0 x 7.00

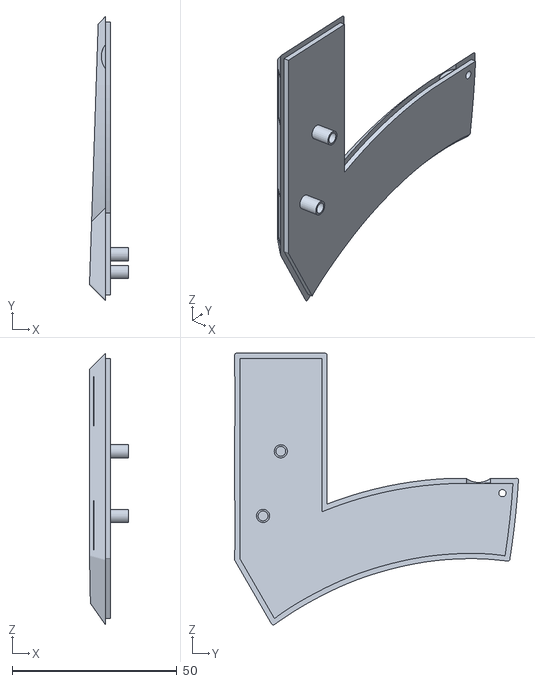
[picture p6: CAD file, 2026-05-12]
case/thumb-bottom-plate.stl
11.8 x 86.2 x 82.4

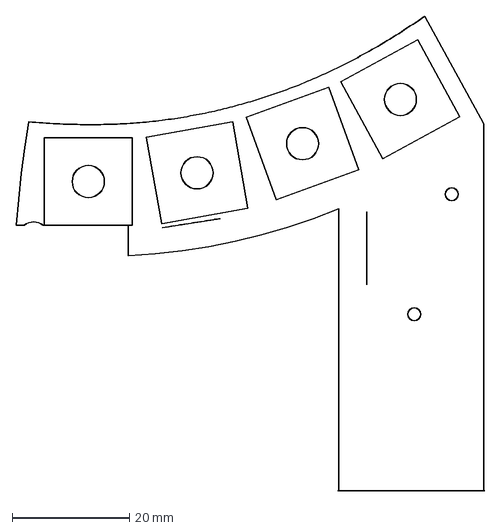
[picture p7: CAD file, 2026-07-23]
v2/pcb/thumb-top.dxf
80.0 x 81.2 mm

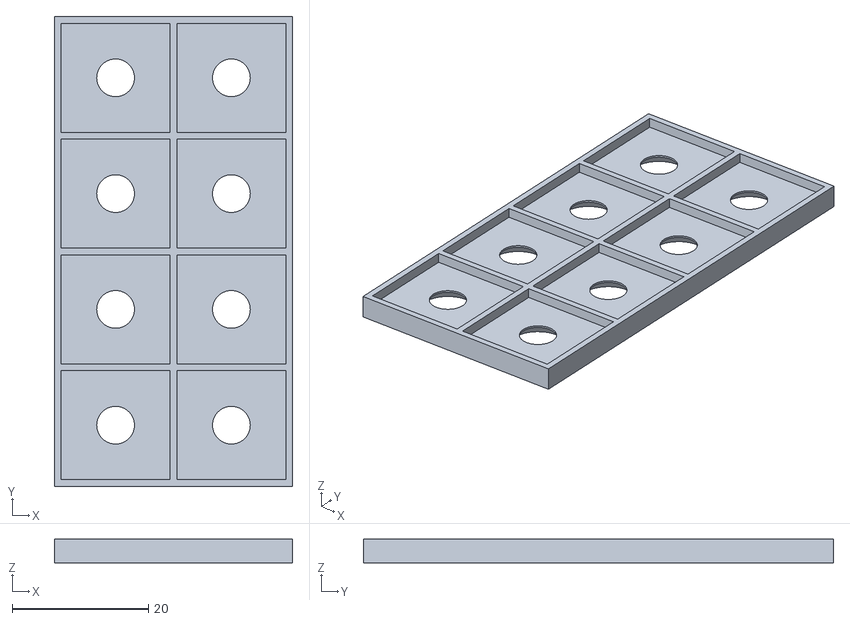
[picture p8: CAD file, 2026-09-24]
v2/case/key-tray-thumb.stl
35.0 x 69.0 x 3.50

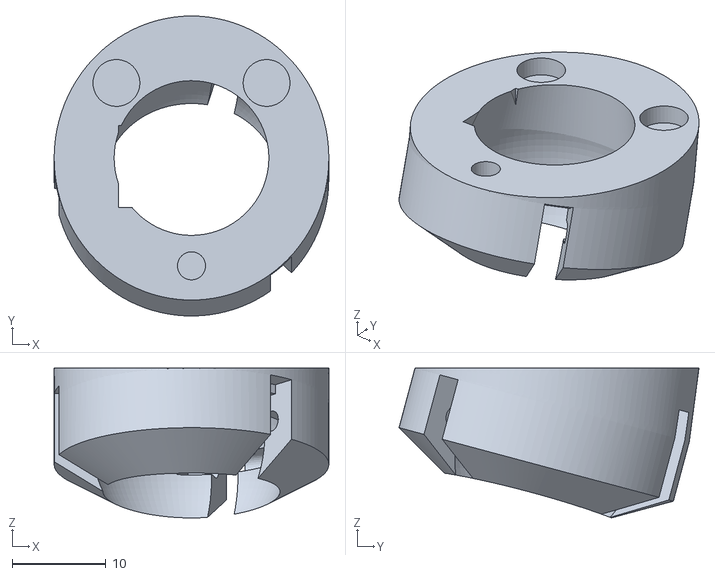
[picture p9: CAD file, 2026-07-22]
v2/case/trabo-case.stl
29.3 x 32.0 x 16.0

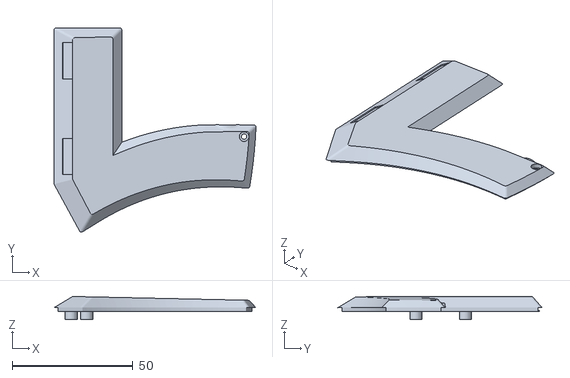
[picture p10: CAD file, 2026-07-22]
v2/case/thumb-bottom-plate.stl
83.5 x 84.5 x 9.53

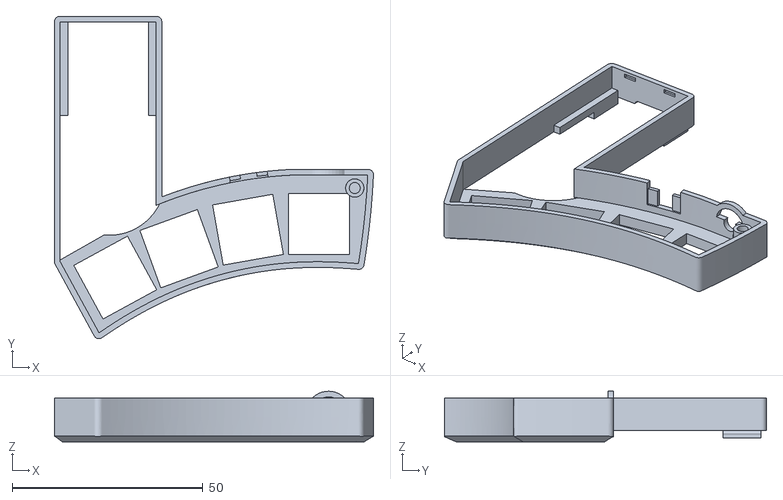
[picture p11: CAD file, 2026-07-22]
v2/case/thumb-side-plate.stl
83.5 x 84.4 x 13.2

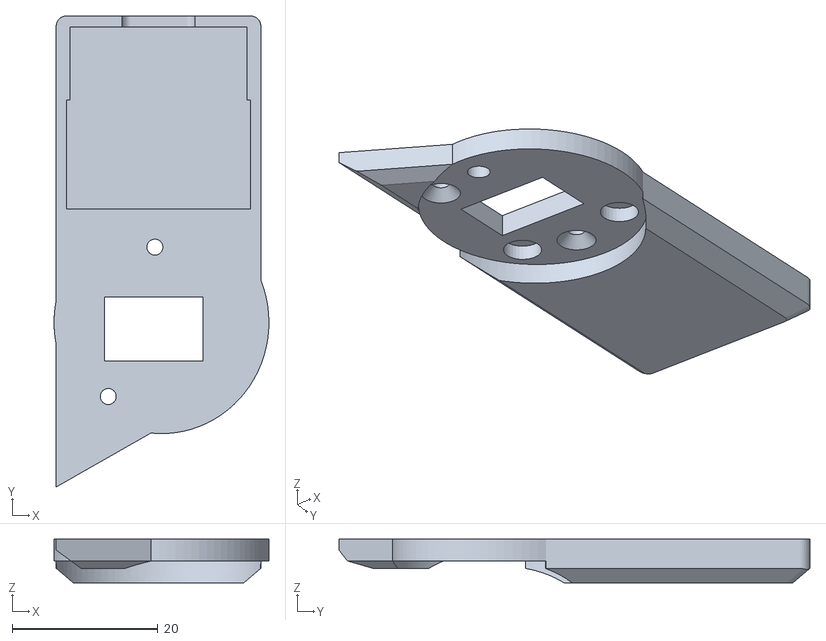
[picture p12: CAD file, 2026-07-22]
v2/case/xiao-cover.stl
29.5 x 64.6 x 6.00

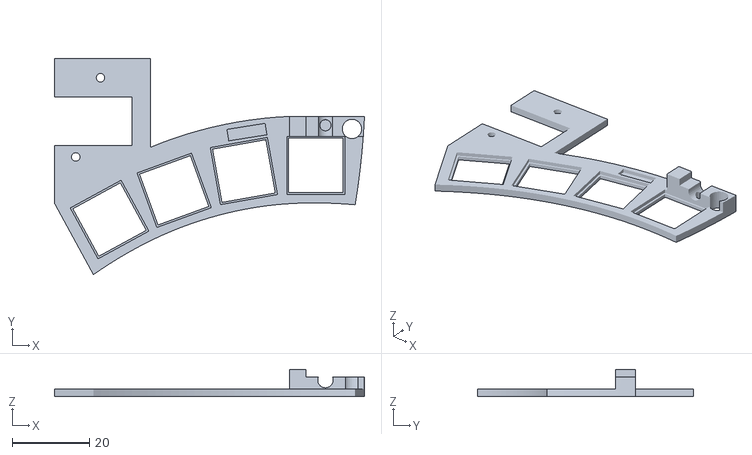
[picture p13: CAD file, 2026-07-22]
v2/case/thumb-top-plate.stl
80.2 x 55.9 x 7.00

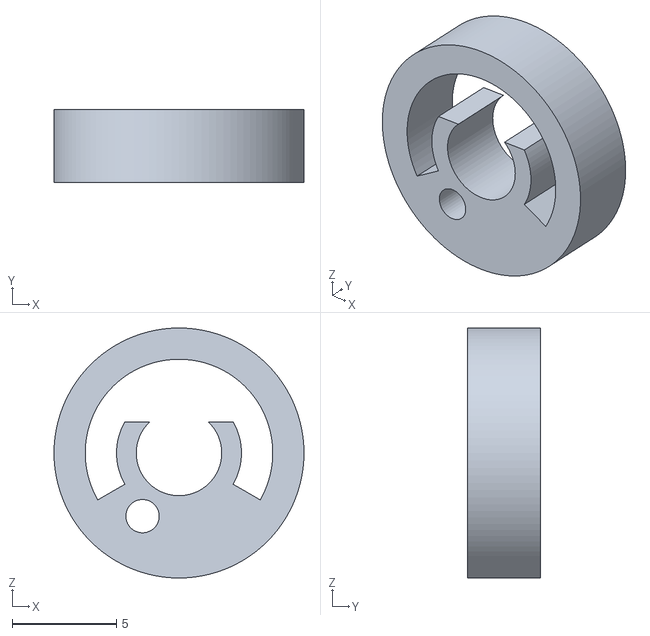
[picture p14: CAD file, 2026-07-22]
v2/case/hinji-cover.stl
12.0 x 3.50 x 12.0

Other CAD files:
case/stl/main-unit/main-side-plate.stl
v1/case/3mf/08-main-top-plate.3mf
v1/case/stl/main-unit/main-unit-left-spacer-top.stl
v1/pcb/dxf/main-unit.dxf
case/stl/common/hinji-cover.stl
case/stl/common/power-switch.stl
case/stl/common/reset-button.stl
case/stl/main-unit/main-bottom-plate.stl
case/stl/main-unit/main-top-plate.stl
case/stl/main-unit/main-unit-left-spacer-bottom1.stl
case/stl/main-unit/main-unit-left-spacer-bottom2.stl
case/stl/main-unit/main-unit-left-spacer-top.stl
case/stl/main-unit/main-unit-right-spacer-bottom1.stl
case/stl/main-unit/main-unit-right-spacer-bottom2.stl
case/stl/main-unit/main-unit-right-spacer-top.stl
case/stl/thumb/thumb-bottom-plate.stl
case/stl/thumb/thumb-side-plate.stl
case/stl/thumb/thumb-top-plate.stl
case/stl/thumb/track-ball-case.stl
case/stl/thumb/xiao-cover-left.stl
case/stl/thumb/xiao-cover-right.stl
v1/case/3mf/01-main-bottom-plate.3mf
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

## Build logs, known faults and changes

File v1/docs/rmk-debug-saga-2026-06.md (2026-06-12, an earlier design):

# kobu RMKファームウェア デバッグ全記録(2026-06-10 〜 06-12)

3日間にわたるRMKファームウェアのデバッグ・修正の全記録。**失敗も含めて実際にやった順番どおり**に記す。
各項目にコミットハッシュを併記(`git show <hash>` で詳細が追える)。

## TL;DR — 最終的に直ったもの

| 問題 | 真の原因 | 最終修正 |
|---|---|---|
| 右トラボの追従遅延(のろのろ) | **splitリンク7.5msとMacリンク15msの2:1電波調波ロック**(共有ラジオ上で位相が固定衝突) | split間隔を8.75msへ(調波外し) `a9ccb0d` |
| 左ボール無反応→右で復活 | macOSのconn interval省電力緩和+回復トリガが右ボール限定 | スクロール側にも再アサート `c1c4212` ほか |
| `;`/`:`の挙動が無茶苦茶 | **MacのKarabiner-Elements「Exchange semicolon and colon」が全キーボード適用**(ファームの出力が常時反転されて見えていた) | kobuをルールから除外+ファーム本体でネイティブ反転 `781e163`〜`7a70299` |
| tap&holdの誤爆・遅延 | rmk-macroのバグ(`= false`が無視される)他、多層 | Option B(balanced+press-edge+バッファリング) `5c772bf`〜`cd70a2a` |
| 高速タイプ後のCmd+Enterが壊れる | Flow TapがCmdサムをBackspace化+リリース時タップ確定 | 純LGui化+Flow Tap廃止+Enter press-edge `52a52d3` `2ce615d` |

---

## Phase 1: トラックボール遅延の根本調査(6/10 日中)

### 症状
1. **S1**: ポインタ(右トラボ)が最初は快適、使っていると「のろのろ」になる
2. **S2**: 左ボールを転がしても無反応。右トラボを動かすと左が復活する謎挙動

### 調査(マルチエージェント workflow、19体)
- 5方向の並列コード調査 → 統合 → 仮説ごとに2レンズ(機構/症状適合)の反証検証
- **確定した事実**:
  - macOSはアイドル時にBLE conn intervalを15ms→30〜50msへ緩める
  - それを戻す唯一のトリガ `KOBU_HOST_CONN_DRIFT` は **PointerProcessor(右ボール)にしか配線されていない**(trackball.rs:798-806)。左ボール・キー入力には無い → S2の「右で復活」と完全一致
  - **重大な地雷**: その再アサートループ自体が**コミットされていないレジストリ内手パッチ**(`r25`)で、`cargo clean -p rmk` で消える状態だった
  - trouBLE 0.5.1はPPCP(0x2A04)未実装(gap.rsでコメントアウト)→ ZMKと違いmacOSに「希望パラメータ」を宣言できていない
  - splitリンクは7.5ms固定・無実(この時点での結論。**半分正しく半分間違いだった** — 後述)
  - スクロールのステップ数学(30カウント/ティック、反転ヒステリシス59カウント、縦軸完全破棄)が左の決定論的無反応に寄与

### 教訓(この時点)
- ワークフロー調査エージェントは読み取り専用(`Explore`)で走らせ、終了後に`git status`とレジストリmtimeを監査する運用が正解だった

---

## Phase 2: 修正シリーズ step0〜step10(6/10夜〜6/11)

「症状別にFWを焼いて1つずつ試す」方式。各stepは累積。

### 成功した土台(6/10夜)
- **step0** `e734c83`: r25手パッチをbuild.rsへ正規移植(ビルド再現性の確保。これをやらないと以後のビルド全てが再アサート無しに退行していた)
- **step1** `c1c4212`: スクロール側(左ボール)にも同じ再アサートを実装 → **S2の構造的解消**
- **step2** `e537601`: trouble-hostへのbuild.rsパッチでPPCP(0x2A04)を公開(ZMKパリティ)。⚠️ macOSのGATTキャッシュにより**再ペアリングしないと見えない** — ユーザーが再ペア前にテストして一度「効かない」と誤判定する一幕あり
- **step3** `3a5a6c5`: スクロール感修正(アイドル減衰300ms・方向反転リセット・**縦軸を縦スクロールへ統合**)

### HWテストで判明した別問題(6/11)
- **Space変換ミス**(タップのつもりがholdになりSpaceが出ない)→ 対話で250msを選択 `046cdac` → **解消**(ただしこの値変更はフラッシュ保存のためclearlayout儀式が必要、という運用も確立)

### のろのろ撲滅の試行錯誤 — **6連敗の記録**(6/11)
診断LED(led-conn-diag)が「リンクは紫=15msで健康」を示し、リンク仮説が崩壊。以降:

1. ❌ **step5a**(実験UF2): ポインタemitゲート `==0`→`<=1`(報告レート66→125Hz化)→ **変化なし**
2. ❌ **step5b**(実験UF2): central通知キュー16→2(鮮度優先)→ **変化なし**
3. 🔶 **step5c** `93dd73f`: splitリンクCE長 0→4ms → ポインタは**変化なし**。ただし**左スクロール問題はここで完治**(副産物)
4. ❌ **step6** `0e0a8df`→revert `b9a1438`: ペリフェラル側イベント合体(coalescing)→ **悪化**(カクカク化)。「滞留の証明」と解釈したが、これは**誤った推論**だった(後の診断LEDは緑=滞留なし)。素直にrevert
5. ❓ **step7** `e186893`: split CE最低予約2ms → 「違いが分からない」
6. ❌ **step8** `40038f3`: SDCコントローラのL2CAPキュー3→8+メモリ増(rmk-macroへのパッチ)→ **変化なし**。診断LEDは緑(ペリフェラル無罪確定)
7. ❌ **step9** `9255f3a`: emitゲート公平化(scroll/pointer同条件)→ **変化なし**

### 決定打はユーザーの切り分け(6/11深夜)
- 発生条件の特定:「**スクロールとポインタを同時/交互に使うと発生**」
- **USB接続+MacのBluetooth完全OFF → ヌルヌル**(=ラジオ上にsplitリンクだけなら問題なし)
- → **共有ラジオ上の電波干渉**と確定。splitの7.5msはMacリンク15msの**ちょうど1/2(調波)**で、位相が悪いと同じsplitイベントが恒常的に潰される(クロックドリフトは分オーダーでしか回らない=「少し置くと治る」はmacOSの再アンカー)
- ✅ **step10** `a9ccb0d`: split間隔7.5→8.75ms(LCM=105ms、衝突が1/12に分散し自己回復)→ **解消!**

### 反省
- 5a〜9の6連敗は「コードを読んで仮説→盲撃ち」の限界。**ゼロコストの物理切り分け(BT-OFFテスト)を最初にやるべきだった**
- CI修正 `a90397c`: build.rsが3クレート(rmk/trouble-host/rmk-macro)をパッチするようになったのに`cargo clean`が rmk だけだった → CIビルドがPPCP/SDC修正を**無言で欠落**させる地雷を塞いだ

---

## Phase 3: tap&hold/セミコロンの泥沼(6/12 深夜〜昼)

### 失敗1: KobitoKeyフレーバー移植 `3e5a862` → revert `b45b1cb`
- KobitoKeyのkeymap実物を読み、lt=tap-preferred / mt=hold-preferred / ホームロウ=balanced の混在を1:1移植
- → **3つ壊れた**: 「git s」→「gits」、言語切替悪化、L+`;`コンボ死亡
- → 全revert。だがこの失敗が次の大発見の入口になった

### 大発見×3 `7576fe7`
1. **rmk-macroのバグ**: プロファイルの`hold_on_other_press = false`は**mode=Noneにコンパイルされ「デフォルト継承」になる**(=R27以来、tap-preferred設定は一度も効いておらず、全キーが実はhold_on_other_pressだった。「git s→git@」「holdが早すぎる」の万年原因)
2. **RMKのコンボはKeyAction完全一致**でマッチ(キーコードではない)→ `"Semicolon"`では`MT(Semicolon,...)`キーに永遠に当たらない=**L+`;`コンボは移植初日から死んでいた**
3. Flow Tap(ストリーム中のmorseキー=即タップ)導入で上記を整合 → 3問題とも解消をユーザー確認

### 失敗2〜4: Shift+`;`即応化の3連敗
- ❌ part1 `a2fb649`: 言語サムをFlow Tap除外 → ダメ
- ❌ part2 `8e7c846`: held側の巻き込み除外 → ダメ
- ❌ **choke-point** `4303eed` → revert `5e489d2`: morseタップ全部をforkテーブル経由に → **大退行**(Shift無しでも`;`が出る)
- ❌ fork-free設計 `b2a86ce`: fork廃止+TD化+layer2に`;` → 「治ってない」

### 真の黒幕の発見(6/12朝、ultracode workflow 18体)
4実験マトリクス(タップ/遅チョード/速チョード×離し順)をコードで再現できない矛盾から、エージェントがホスト側を捜索:

> **MacのKarabiner-Elementsに「Exchange semicolon and colon」ルールが有効(デバイス指定なし=kobuにも適用)。画面の`;`/`:`は常にデバイス出力の反転だった。**

- 全時代の不可解な観測(choke後の常時`;`、fork-freeの両逆転)が「正しい出力のKarabiner反転」として完全に再現
- ホストレイアウトはANSI(com.apple.keyboardtypeで確認)。JIS仮説は棄却
- ✅ `781e163`: ファームは素のUS出力に戻し、Karabinerに反転させる(当時の方針)+**おまけの大発見**: 純正`clear_layout`は**combo/fork/morseのVial保存領域を消していなかった**(boot時にfill_vecパディング後、保存スロットで上書きされる)→ clearlayoutを完全リシンク化するパッチ追加
- → ユーザー確認「サーガ完結」

### 教訓
- **キー出力が不可解なときは、ファームを疑う前に`karabiner.json`を確認する**(本リポジトリ最大の教訓)
- 実験マトリクス(ユーザーの実機観測)をコードで再現できない場合、その矛盾自体が「見えていないレイヤー」の存在証明

---

## Phase 4: ネイティブ反転・かな切替・Cmd+Enter(6/12 午前〜夕方)

### 要望: 反転をキーボード本体へ+Karabinerはkobu除外
- karabiner.jsonの該当ルールに`device_unless`(VID 19279/PID 16985+product名"kobu")を追加(バックアップ: `karabiner.json.bak-20260612`)
- `9fc8d17`: ネイティブ反転v2(タップ→WM変換+チョードはShiftマスク)+かな用Ctrl+英数コンボ

### 失敗5〜6: press-edgeが効かない2連敗 → 機構の発見
- ❌ v2: 「全部ダメ」→ EventViewerでデバイスID一致を確認(除外設定は正しい)
- ❌ v3 `f47580f`: **`;`キーはL+`;`コンボのメンバーなので押下が`WaitingCombo`でパークされ、None-armのpress-edge処理が一度も実行されていなかった**ことを発見し、バッファmatch前にhoist → それでもダメ
- ユーザーの神観測:「**電源を入れ直した直後(Karabinerが掴む前)は`;`が打てる**」=デバイス出力は正しい
- EventViewer実データで確定: **「shift解除とsemicolon押下を同一HIDレポートに同居」させるマスク方式は、ホスト側でkeydownが先に処理されて無効化される**(動いたり動かなかったりは順序の運)
- ✅ **v5** `7a70299`: マスクを**独立レポートとして先に送出** → **`;`解消!**
- 途中のv4 `109e3b5`(かな救済: flow-tapされたSpace保持中に言語サム→Backspaceで取消+Language1直接送出)は機能したが、Ctrl+英数コンボがサムを50msパークし「Backspaceが次のキーで出る」奇妙な見え方に → コンボ撤去

### Option B: tap&holdの最終形(ユーザー選択)
スペースの「一瞬出て消える」ちらつき(v4救済)がイマイチ → 3案提示しB(KobitoKey方式)を選択:
- `5c772bf`: LT専用プロファイル(tap-preferred)+LTのFlow Tap除外+**RMKに無かった「未確定中の後続キーを順序保証でバッファ」をパッチ追加**(ZMKは持っている。parity時代の「gits」の真の機構)
- ❌ ただし素のtap-preferredは**かな切替が200ms待ちで「鬼遅い」**
- `404ecb3`: balanced(permissive_hold)化 → 「かなりいい、あとほんの少し」
- ✅ **v6** `cd70a2a`: press-edge×2(言語サム押下でレイヤー即確定+ストリーム中のLanguage1は押下エッジで即送出)→ **「完璧!」**

### Cmd+Enter問題(6/12夕方)
- 症状: 高速タイプ→Cmd+Enterが「Backspace+Enter」になる
- 原因①: **Flow TapがCmdサム(MT(Backspace,LGui))を即Backspaceタップ化**
- ✅ `52a52d3`: Cmdサムを**純LGuiに変更**(ユーザー指示。タップBSは未使用)+**Flow Tap全廃**(全用途が別機構で代替済みになっていた)
- 原因②: 純Cmd化でKarabinerの「Cmd単体押し→かな」ルールがkobuで発火 → 言語系2ルールにもkobu除外を追加(フラッシュ不要、即時有効)
- 原因③: 「Cmdを先に離すと素のEnter」= balancedのEnterはリリース時にタップ確定するため
- ✅ **v7** `2ce615d`: **Enterチョードのpress-edge化**(修飾キー保持中のEnter押下=その瞬間に確定。Spaceは対象外=Cmd+Space誤爆/Cmd+レイヤー数字を保護)→ **「全部OK!」**

---

## Phase 5: マウス操作(クリック)の救済(6/12 夕方、別セッション) `d80002d`

### 症状(2件)
1. **「ポインタをほとんど静止した状態じゃないとちゃんとクリック出来ない」** — 動きながらクリックするとカーソルが跳んで狙いが外れる
2. **「静止するために微調整しているとオートマウスレイヤーが切れちゃってクリックできなくなる」** — 止めて狙っている間にレイヤー4が消え、クリックのつもりが文字打鍵になる

### 原因
1. CLICK_FREEZE(40ms)は押下時の玉の機械的ブレを**pend_\*に貯金**し、freeze明けに**1レポートで一括放出**していた → ホスト視点では mousedown→ジャンプ→mouseup の**マイクロドラッグ**(クリック判定が外れる)
2. アイドルタイムアウト150msが、人間の「静止→狙う→指をボタンへ動かす」の所要(約200〜400ms)より**短かった**。皮肉なことに、150msに切り詰めた当時の定数コメントの⚠️警告が**この失敗を正確に予言していた**

### 修正(`d80002d`)
1. **クリック運動量の破棄**: freeze 40→80ms(玉の機械的セトリングをカバー)+貯金ではなく**破棄**(press edgeでpend_\*をゼロ化)。押してからのドラッグは無傷(掴み位置=押下時点)
2. **オートマウスホールドの文脈対応再設計**:
   - アイドル窓 600ms(クリック準備に十分な幅)→ 後日「有効時間が長い」とのフィードバックで 400ms(`ad4c7e4`)→**300ms** に追い込み。即キルが効かないのは**レイヤー4の非透過位置**(Y/U/I/O のマウスボタン等)だけなので、窓の長さ=「マウス直後のタイプが誤クリックに化ける」露出時間。300msは人間の静止→照準→クリック(約200〜400ms)の下限ギリギリ＝これ以上削ると150ms時代のクリック不能が再発する床
   - **再アーム条件**: 動き/マウスボタンのエッジ(ダブルクリック連鎖が生存)/ボタン保持(ドラッグは無期限)/非タイピングキー押下(レイヤー4のCmd+C/V/Tabチョードや単独修飾でレイヤーが落ちない)
   - **タイピング即キル**: 「150msの短さ」が本来担っていた“すぐタイピングに戻れる”は、タイムアウトではなく**即時検出**に置き換え — 新レジストリパッチ `patch_rmk_typing_tick`(keymap.rs `get_action_with_layer_cache` で、**透過なレイヤー4スロットを下の層へフォールスルーした非修飾キー押下**=本物のタイピング、を `KOBU_LAST_TYPING_TICKS` に刻印)+25msポーリングのホールドループが1ポーリング以内にレイヤーを落とす
   - 設計判断: レイヤー4は左手側が高密度(Cmd+C/V/Tab等)なので「どのキー押下でも殺す」は誤り。「**透過フォールスルー=タイピング**」が正しい判別子
   - 再開1打目は透過でそのまま正しく打鍵され、2打目以降はキル後のベースレイヤーに着地(25ms << 打鍵間隔80ms+)

### 結果
ユーザー確認「**かなり良くなった**」。レビュー所見: パッチ対象(battery.rs/keymap.rs)は既存パッチ群(keyboard.rs/morse.rs系)とアンカー非干渉、マーカー冪等の規律も維持、`cargo clean -p rmk` 実施済み・全4 UF2再生成済みで健全。

### 追補(同日のフォローアップ、ユーザー確認「good」)
- **レイヤー4左手の全透過化**(ユーザー要望): 旧レイヤー4左手の Cmd+[ / Cmd+] / TD(2) Shift / Tab+LGui / Ctrl / Cmd+C/V クラスタを撤去し、左手3行を全部 `_` に(親指行は元々透過)。これで「透過フォールスルー=タイピング」の即キル判定が**左手全域**に効く — マウス操作直後でも左手1打目から正常打鍵+レイヤー即落ち。右手の MouseBtn1/2/2/3 だけレイヤー4に残存(マウス中のクリックはレイヤーで解決されるのでキルされない)。TD(2)は未参照になったが TD(0)/TD(1) のインデックス維持のため定義は残置。キーマップ変更なので反映には clearlayout 儀式が必要
- **アイドル窓の追い込み**: 600→400→**300ms**(経緯は上記「修正」の項)

---

## 失敗から得た技術的教訓(再発防止メモ)

1. **ホストを先に疑え**: キー出力の怪奇現象は `~/.config/karabiner/karabiner.json` を最初に確認。Karabinerルールはデバイス無指定だと自作キーボードにも適用される
2. **rmk-macro 0.7.1**: morseプロファイルのモードフラグに`= false`を書いても**無視されてデフォルト継承**になる。有効にしたいモードだけ`= true`で書く
3. **RMKのコンボはKeyAction完全一致**: morseキー(MT/TD)をコンボに入れるならコンボ定義にフルアクション文字列を書く。またコンボメンバーのmorseキーは押下が`WaitingCombo`でパークされ、**押下時(None-arm)の特殊処理が走らない**
4. **HIDのmod-morph式マスク**: 修飾解除とキー押下を同一レポートに入れてはいけない(ホストの処理順が未定義)。**修飾だけの独立レポートを先に送る**
5. **RMKのnormal/balancedモードは後続キーをバッファしない**(ZMKはする)→ 順序逆転(「gits」)。`patch_rmk_normal_mode_buffering`で追加済み
6. **純正clear_layoutはcombo/fork/morseのVial保存を消さない** → `patch_rmk_clearlayout_resync_vial_tables`で完全リシンク化済み
7. **ビルド運用**: build.rsはrmk/trouble-host/rmk-macroの3クレートをレジストリ内パッチする。新パッチ追加時は対応する`cargo clean --release -p <crate>`が必須(CIは対応済み)
8. **フラッシュ運用**: keymap/morse/combo変更=clearlayout→通常の儀式(BLEボンドは保持される。ボンドごと消すのはclear_storage)。コード(レジストリパッチ)のみの変更=普通の上書きでOK
9. **定数コメントの⚠️警告は予言**: AUTO_MOUSE_TIMEOUT 150ms化のときに書いた「stop→aim→clickでレイヤーが落ちる」警告が3日後にそのまま現実化した。トレードオフを切り詰めるときは、警告コメントを残すだけでなく代替手段(今回はタイピング即キル)とセットで設計する
10. **盲撃ちの前に物理切り分け**: 「USB+BT-OFF」「電源直後のKarabiner未把握ウィンドウ」「Karabiner-EventViewer」のようなゼロコスト観測が、6連敗ぶんの試行錯誤より速い

## 最終構成(2026-06-12時点の挙動マップ)

| 操作 | 確定タイミング |
|---|---|
| 変換のSpaceタップ | リリース時(KobitoKey同等) |
| かな切替(Space+英数) | 英数サムに**触れた瞬間**(press-edge×2) |
| 数字レイヤー(Space+キー) | 相手キーのリリース時(balanced) |
| Cmd+Enter / Shift+Enter | Enter**押下の瞬間**(離し順不問) |
| Shift+`;` → `;` / タップ → `:` | 押下エッジ+独立レポートマスク(本体実装、ホスト非依存) |
| Cmdサム | 純LGui(tap無し) |
| Flow Tap | 廃止 |
| クリック(動きながら) | 押下エッジで運動量破棄(80ms)— マイクロドラッグ消滅 |
| オートマウスレイヤー | アイドル300ms+クリック/ドラッグ/チョードで再アーム+タイピングで即キル(≤25ms) |
| Karabiner | `;`/`:`交換・Ctrl単体・Cmd単体の3ルールからkobuを除外(他デバイスは従来どおり) |

主要な独自パッチ(build.rs内、すべてマーカー冪等): r25再アサート / PPCP / split CE長+予約 / split間隔8.75ms / SDCキュー8 / shift-chord press-edge(v3+v5) / かな救済(休眠) / kana press-edge / enter press-edge / normal-modeバッファリング / flow-tap除外群 / clearlayout完全リシンク / typing-tick(タイピング即キル)

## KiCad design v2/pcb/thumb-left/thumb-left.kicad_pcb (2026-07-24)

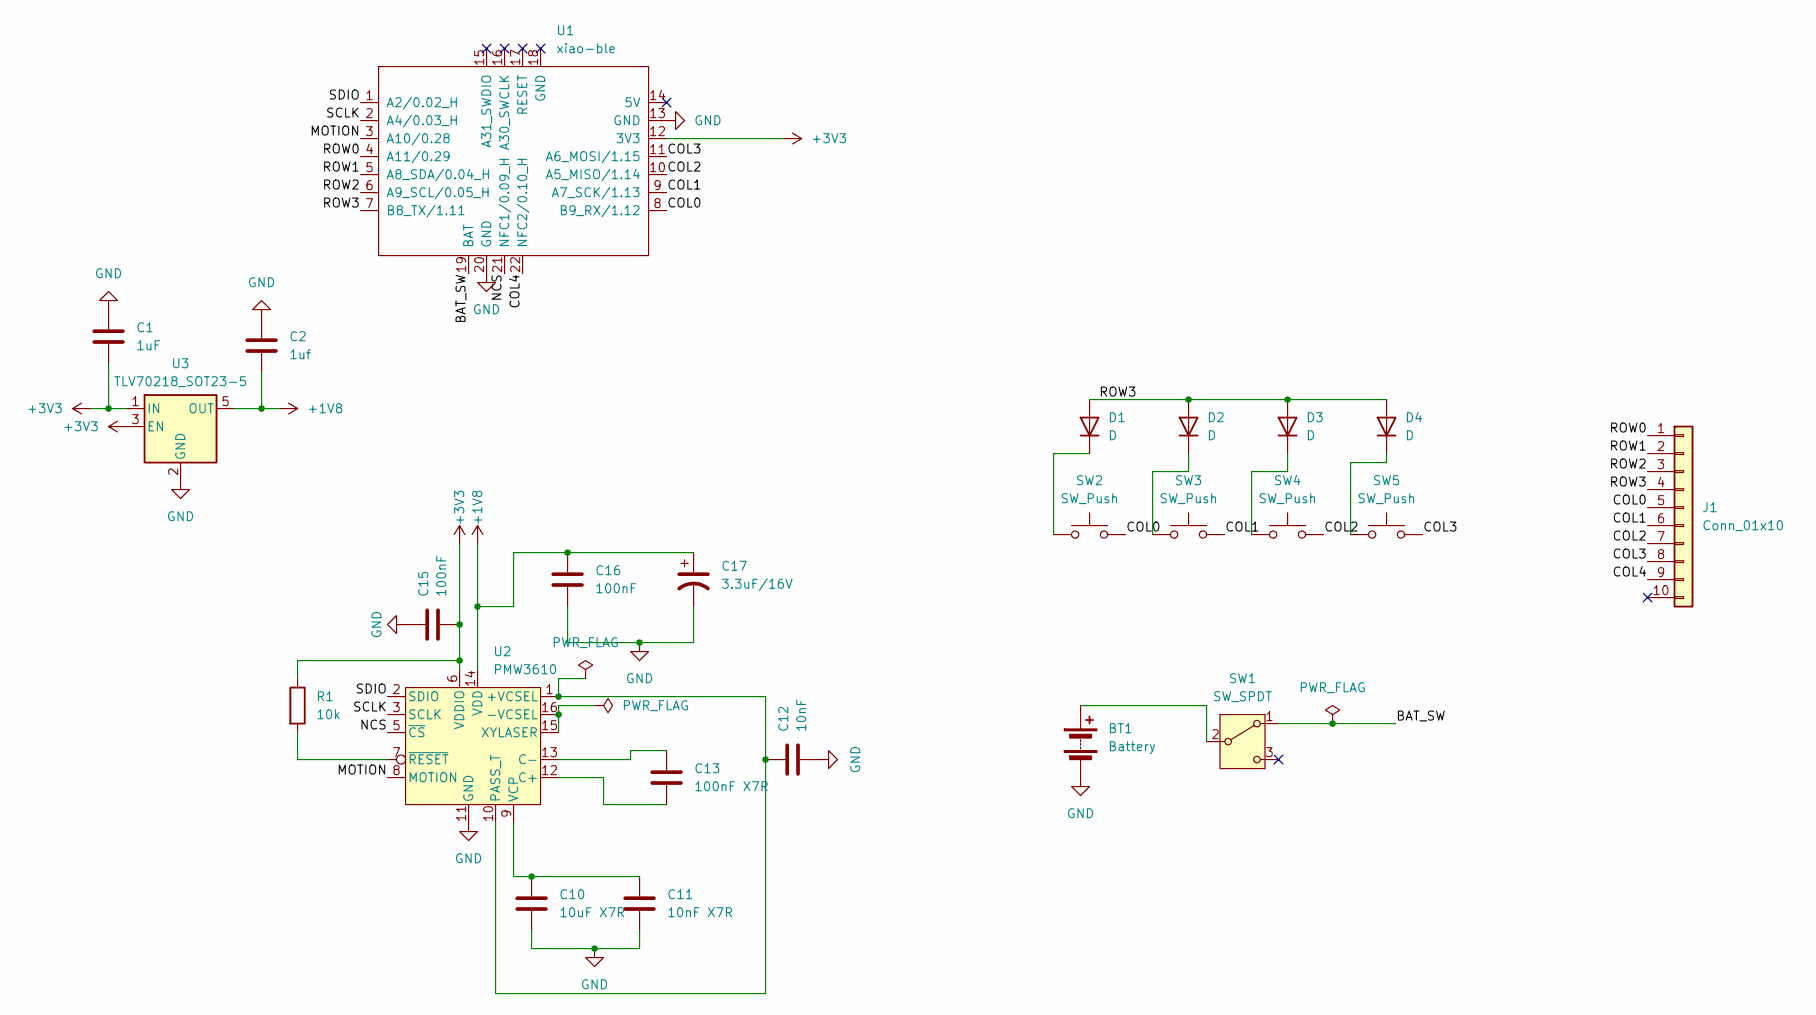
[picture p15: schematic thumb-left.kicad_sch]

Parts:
BT1: Battery; Molex_PicoBlade_53261-0271_1x02-1MP_P1.25mm_Horizontal
C1: 1uF; C_0402_1005Metric
C2: 1uf; C_0402_1005Metric
C10: 10uF X7R; C_0603_1608Metric
C11: 10nF X7R; C_0402_1005Metric
C12: 10nF; C_0402_1005Metric
C13: 100nF X7R; C_0402_1005Metric
C15, C16: 100nF; C_0402_1005Metric
C17: 3.3uF/16V; C_0603_1608Metric
D1, D2, D3, D4: D; D_SOD-123
J1: Conn_01x10; Hirose_FH12-10S-0.5SH_1x10-1MP_P0.50mm_Horizontal
R1: 10k; R_0603_1608Metric
SW1: SW_SPDT; TGSW_MSK-12D19
SW2, SW3, SW4, SW5: SW_Push; SW_Hotswap_Kailh_Choc_V2_1.00u
U1: xiao-ble; XIAO_nRF52840_wBAT_wNFC_1
U2: PMW3610
U3: TLV70218_SOT23-5; SOT-23-5

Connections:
+1V8: C2.2, C16.1, C17.1, U2.14 (VDD), U3.5 (OUT)
+3V3: C1.2, C15.2, R1.1, U1.12 (3V3), U2.6 (VDDIO), U3.1 (IN), U3.3 (EN)
/BAT_SW: SW1.1 (A), U1.19 (BAT)
/COL0: J1.5, SW2.2, U1.8 (B9_RX/1.12)
/COL1: J1.6, SW3.2, U1.9 (A7_SCK/1.13)
/COL2: J1.7, SW4.2, U1.10 (A5_MISO/1.14)
/COL3: J1.8, SW5.2, U1.11 (A6_MOSI/1.15)
/COL4: J1.9, U1.22 (NFC2/0.10_H)
/MOTION: U1.3 (A10/0.28), U2.8 (MOTION)
/NCS: U1.21 (NFC1/0.09_H), U2.5 (~CS)
/ROW0: J1.1, U1.4 (A11/0.29)
/ROW1: J1.2, U1.5 (A8_SDA/0.04_H)
/ROW2: J1.3, U1.6 (A9_SCL/0.05_H)
/ROW3: D1.2 (A), D2.2 (A), D3.2 (A), D4.2 (A), J1.4, U1.7 (B8_TX/1.11)
/SCLK: U1.2 (A4/0.03_H), U2.3 (SCLK)
/SDIO: U1.1 (A2/0.02_H), U2.2 (SDIO)
GND: BT1.2 (-), C1.1, C2.1, C10.1, C11.1, C12.2, C15.1, C16.2, C17.2, U1.13 (GND), U1.20 (GND), U2.11 (GND), U3.2 (GND)
unnamed: BT1.1 (+), SW1.2 (B)
unnamed: D1.1 (K), SW2.1
unnamed: D2.1 (K), SW3.1
unnamed: D3.1 (K), SW4.1
unnamed: D4.1 (K), SW5.1
unnamed: C12.1, U2.1 (+VCSEL), U2.10 (PASS_T)
unnamed: U2.15 (XYLASER), U2.16 (-VCSEL)
unnamed: C13.2, U2.12 (C+)
unnamed: C13.1, U2.13 (C-)
unnamed: C10.2, C11.2, U2.9 (VCP)
unnamed: R1.2, U2.7 (~RESET)

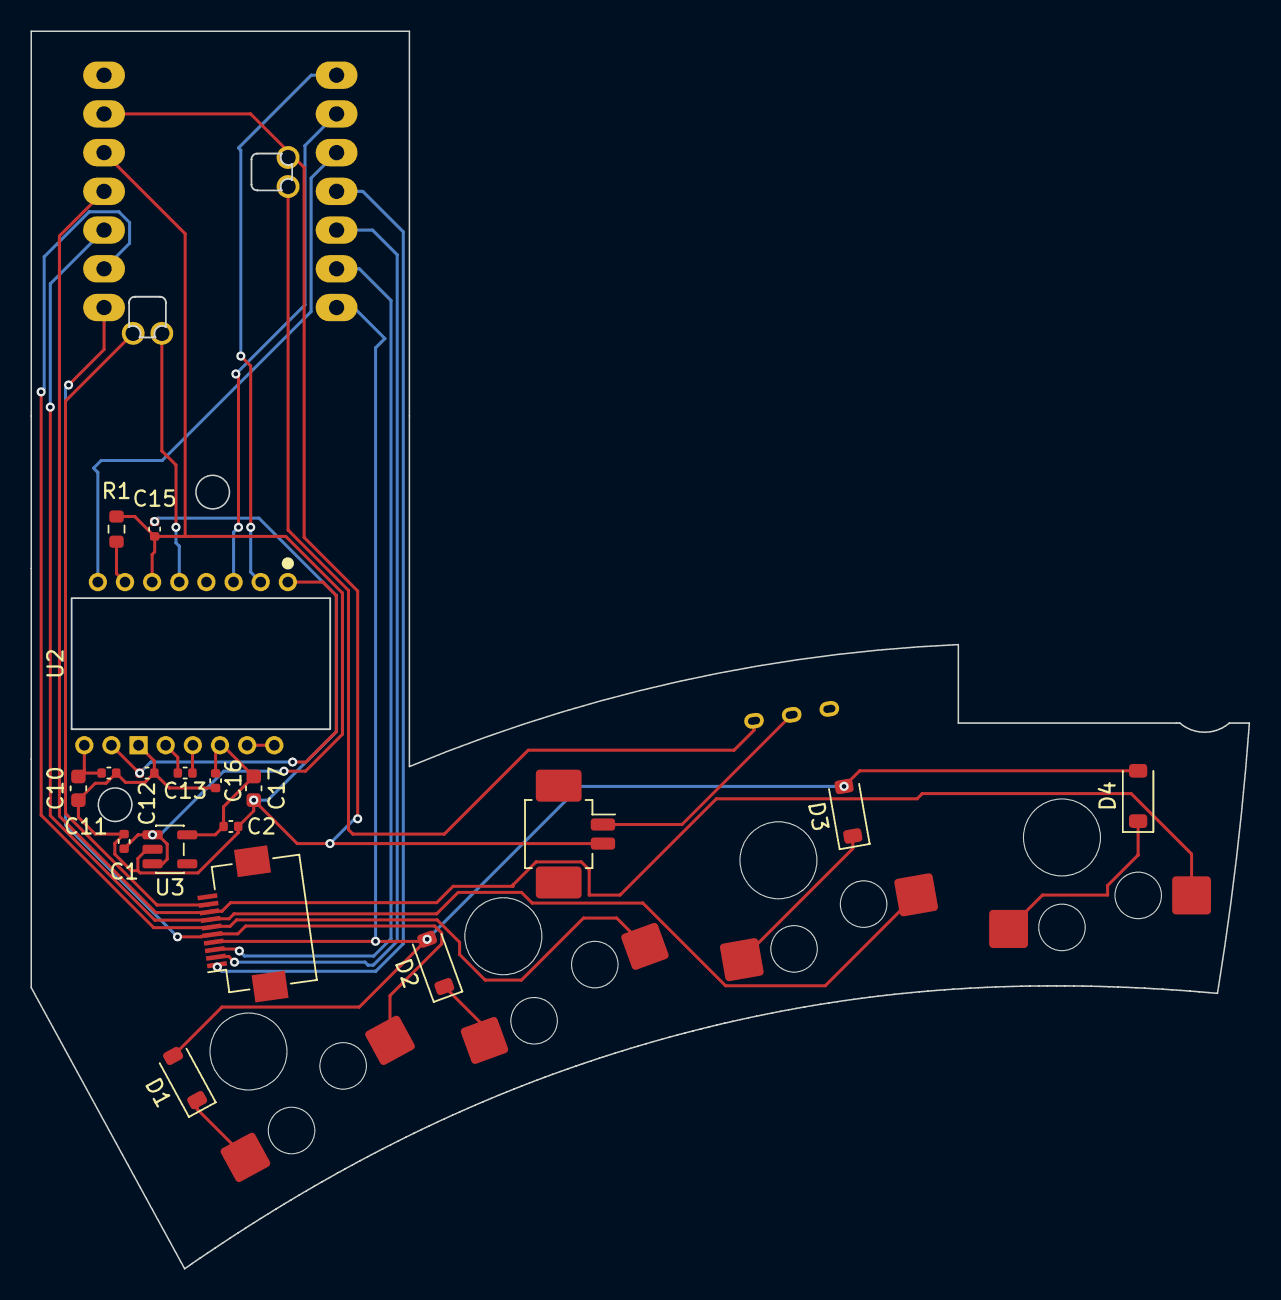
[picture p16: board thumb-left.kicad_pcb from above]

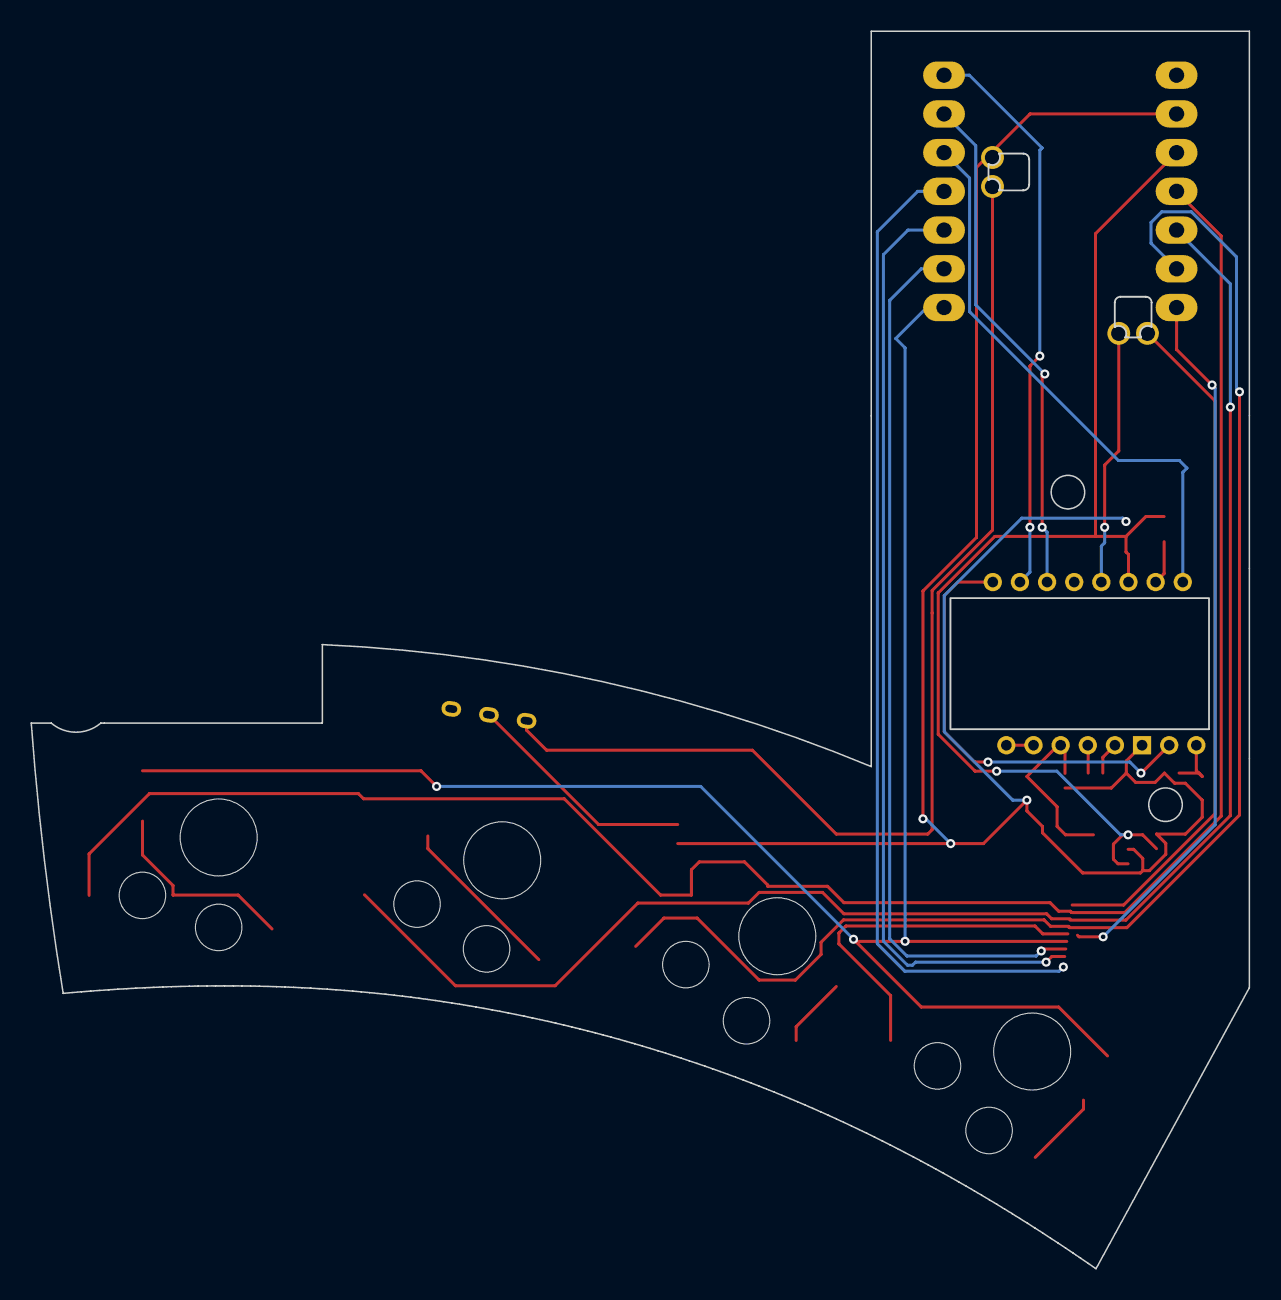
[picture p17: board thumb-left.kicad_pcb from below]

Board: 2 copper layers, 79.9 x 81.2 mm, 24 parts (5 on the bottom side), 28 nets.

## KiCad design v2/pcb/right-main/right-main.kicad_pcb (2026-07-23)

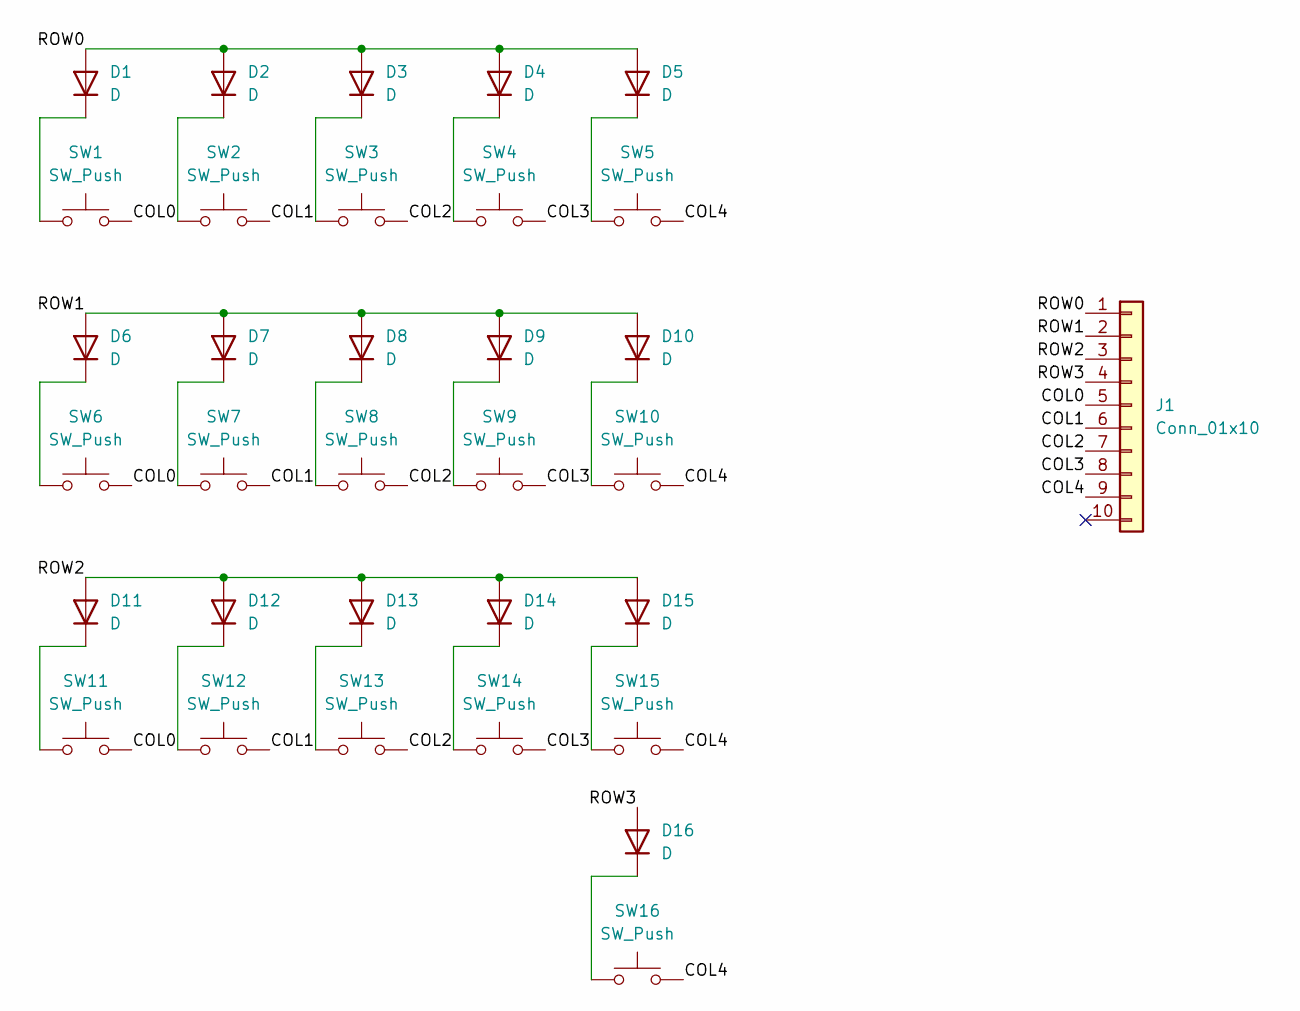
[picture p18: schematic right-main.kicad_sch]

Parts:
D1, D2, D3, D4, D5, D6, D7, D8, D9, D10, D11, D12, D13, D14, D15, D16: D; D_SOD-123
J1: Conn_01x10; Hirose_FH12-10S-0.5SH_1x10-1MP_P0.50mm_Horizontal
SW1, SW2, SW3, SW4, SW5, SW6, SW7, SW8, SW9, SW10, SW11, SW12, SW13, SW14, SW15, SW16: SW_Push; SW_Hotswap_Kailh_Choc_V2_1.00u

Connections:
/COL0: J1.5, SW1.2, SW6.2, SW11.2
/COL1: J1.6, SW2.2, SW7.2, SW12.2
/COL2: J1.7, SW3.2, SW8.2, SW13.2
/COL3: J1.8, SW4.2, SW9.2, SW14.2
/COL4: J1.9, SW5.2, SW10.2, SW15.2, SW16.2
/ROW0: D1.2 (A), D2.2 (A), D3.2 (A), D4.2 (A), D5.2 (A), J1.1
/ROW1: D6.2 (A), D7.2 (A), D8.2 (A), D9.2 (A), D10.2 (A), J1.2
/ROW2: D11.2 (A), D12.2 (A), D13.2 (A), D14.2 (A), D15.2 (A), J1.3
/ROW3: D16.2 (A), J1.4
unnamed: D1.1 (K), SW1.1
unnamed: D2.1 (K), SW2.1
unnamed: D3.1 (K), SW3.1
unnamed: D4.1 (K), SW4.1
unnamed: D5.1 (K), SW5.1
unnamed: D6.1 (K), SW6.1
unnamed: D7.1 (K), SW7.1
unnamed: D8.1 (K), SW8.1
unnamed: D9.1 (K), SW9.1
unnamed: D10.1 (K), SW10.1
unnamed: D11.1 (K), SW11.1
unnamed: D12.1 (K), SW12.1
unnamed: D13.1 (K), SW13.1
unnamed: D14.1 (K), SW14.1
unnamed: D15.1 (K), SW15.1
unnamed: D16.1 (K), SW16.1

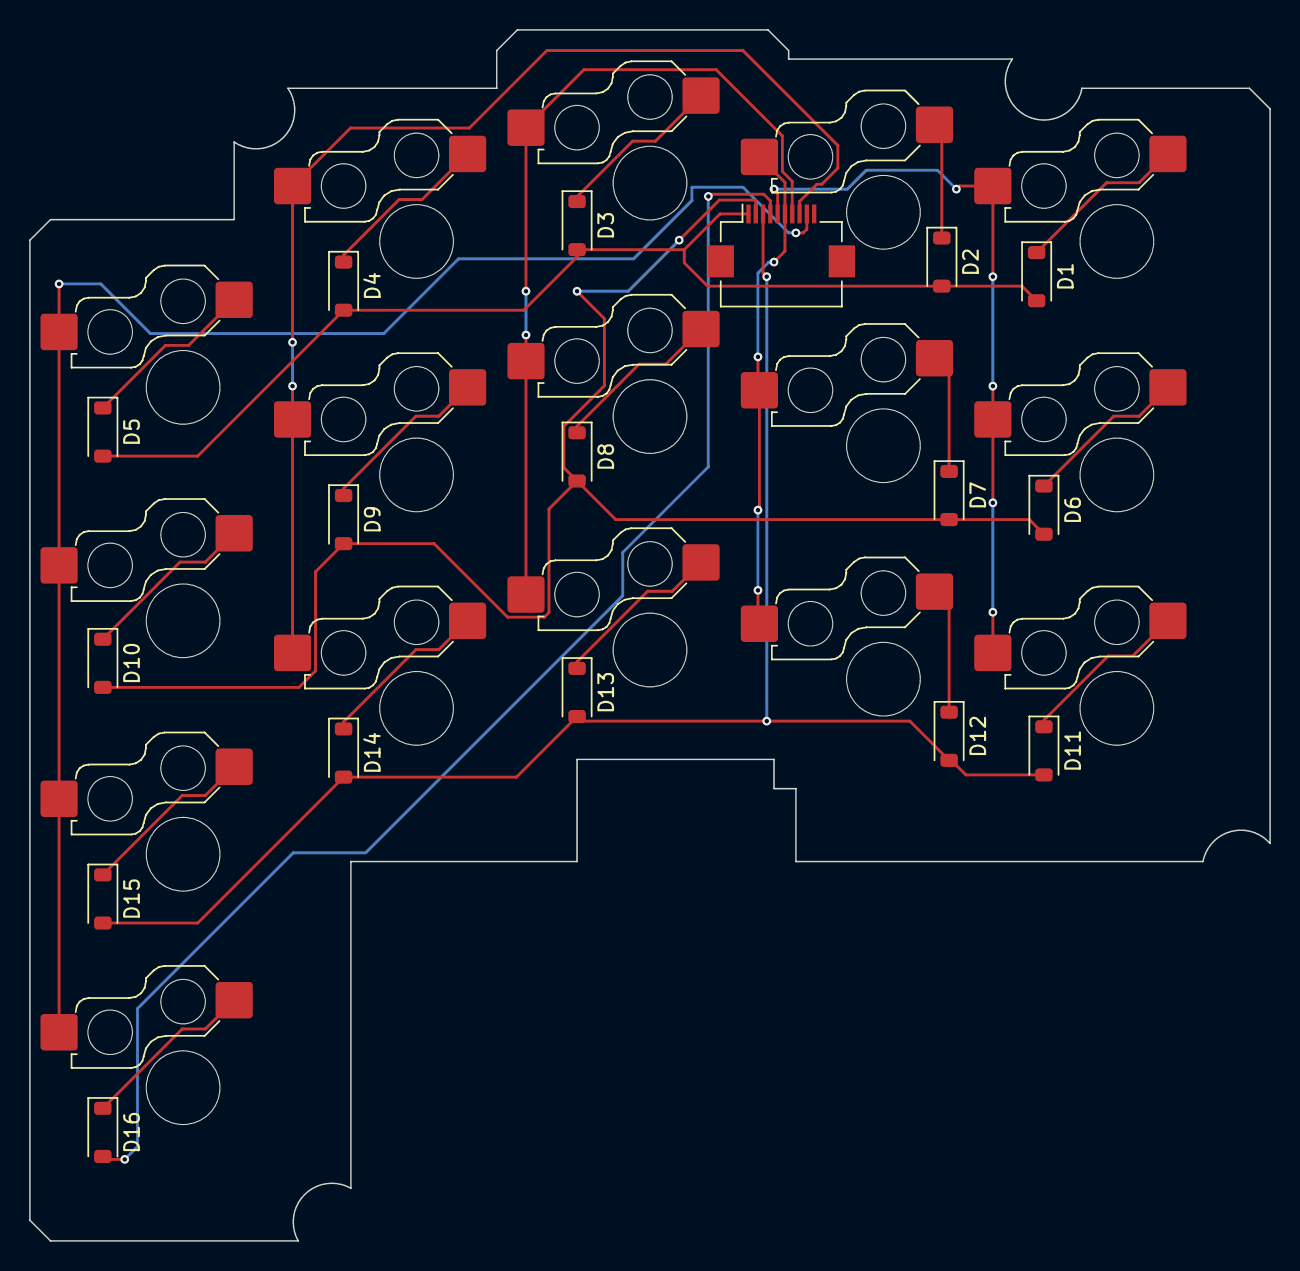
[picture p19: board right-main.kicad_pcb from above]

Board: 2 copper layers, 85.0 x 83.0 mm, 33 parts (16 on the bottom side), 25 nets.

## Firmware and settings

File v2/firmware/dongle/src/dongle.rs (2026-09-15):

//! Prospector display DONGLE — the split CENTRAL of the kobu2 dongle topology.
//!
//! USB-connected to the host; holds two BLE central links (peripheral id 0 =
//! RIGHT half, id 1 = LEFT half); no keys or trackball of its own (the 0x0
//! matrix from keyboard.toml parks forever under async_matrix); drives the
//! Prospector's ST7789V2 status screen (src/display.rs).
//!
//! The processor chain and helper tasks are the classic central's
//! (../rmk/src/{trackball,config,status_led}.rs shared via #[path]) with two
//! substitutions:
//!
//!   * No local AxisRelabel wrapper — the LEFT half's Joystick events arrive
//!     already relabeled X→H/Y→V by the registry patch
//!     `patch_rmk_peripheral_manager_source_disambiguation` (id 1 only), so
//!     ScrollProcessor still claims H/V (left ball = scroll) and
//!     PointerProcessor claims X/Y (right ball = pointer) unchanged.
//!   * `DongleBatteryRouter` replaces `CentralBatteryTagger` +
//!     `KobuBatterySourceTap`: the dongle has no battery (its macro-generated
//!     adc_device is discarded — USB-powered, P0_31 floats), and both halves'
//!     forwarded samples are routed into the SAME Via 0xC0 atomics as the
//!     classic topology (0x10 = left, 0x11 = right), min() forwarded to BAS.
//!
//! The onboard XIAO RGB LED keeps the classic StatusLedController as a
//! boot/bring-up diagnostic alongside the screen (with two peripherals its
//! "split connected" facet reflects whichever half reported last — the screen
//! is the authoritative per-half view).

#![no_main]
#![no_std]

#[path = "../../rmk/src/config.rs"]
mod config;
mod display;
mod dongle_battery;
mod set_token;
#[path = "../../rmk/src/status_led.rs"]
mod status_led;
#[path = "../../rmk/src/trackball.rs"]
mod trackball;

use rmk::macros::rmk_central;

#[rmk_central]
mod keyboard_central {
    use crate::dongle_battery::DongleBatteryRouter;
    use crate::status_led::StatusLedController;
    use crate::trackball::{
        PeriphScrollRelabel, PointerProcessor, ScrollProcessor, run_auto_mouse_layer,
        run_input_gate_central,
    };

    // Onboard RGB LED (P0.26/P0.30/P0.06) as a bring-up diagnostic. Claimed
    // from `p` here; controller initializers run before the entry body.
    #[controller(poll)]
    fn status_led() {
        use ::embassy_nrf::gpio::{Level, Output, OutputDrive};
        let red = Output::new(p.P0_26, Level::High, OutputDrive::Standard);
        let green = Output::new(p.P0_30, Level::High, OutputDrive::Standard);
        let blue = Output::new(p.P0_06, Level::High, OutputDrive::Standard);
        StatusLedController::new(red, green, blue)
    }

    // Override the macro-generated entry to
    //   1. drop the dongle's own input devices (0x0 matrix, floating-pin ADC,
    //      and the two placeholder Pmw3610Processors the macro emits for the
    //      peripherals' trackballs),
    //   2. run [DongleBatteryRouter, PeriphScrollRelabel, Scroll, Pointer,
    //      battery_processor] as the chain (PeriphScrollRelabel remaps the
    //      right ball to scroll while H+J is held),
    //   3. run TWO peripheral managers (id 0 = right at col offset 5, id 1 =
    //      left at col offset 0 — must match the [[split.peripheral]] order),
    //   4. join the Prospector display task on the pins the Prospector
    //      adapter wires to SPIM3 (see src/display.rs).
    #[Overwritten(entry)]
    async fn rmk_entry() {
        use ::rmk::controller::PollingController;
        use ::rmk::input_device::Runnable;

        // Discard the macro-generated bindings this topology doesn't run:
        // the placeholder processors for the halves' PMW3610s (replaced by
        // Scroll/PointerProcessor), the dongle's own ADC (no battery), and
        // the 0x0 matrix (nothing to scan; peripheral managers feed the
        // channels directly).
        let _ = right_processor;
        let _ = left_processor;
        let _ = adc_device;
        let _ = matrix;

        let mut battery_router = DongleBatteryRouter::new(&keymap);
        let mut periph_scroll_relabel = PeriphScrollRelabel::new(&keymap);
        let mut scroll_processor = ScrollProcessor::new(&keymap);
        let mut pointer_processor = PointerProcessor::new(&keymap);

        // Same boot pointer-CPI multiplier as the classic central (1.5×,
        // live-tunable via kobu-config 0xC0 id 0x01; not persisted).
        ::rmk::input_device::battery::KOBU_TRACKBALL_CPI
            .store(1500, ::core::sync::atomic::Ordering::Relaxed);

        // Multi-set independence: only scan-bind halves advertising THIS
        // set's token (must run before scan_peripherals starts below).
        crate::set_token::apply_split_set_token();
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

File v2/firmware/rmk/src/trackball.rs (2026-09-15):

//! Trackball glue for kobu (both halves).
//!
//! LEFT half (= central, local PMW3610) drives SCROLL.
//! RIGHT half (= peripheral, forwarded PMW3610) drives POINTER motion.
//!
//! ## Why the axis relabel
//!
//! RMK 0.8's split protocol forwards peripheral pointing events to the
//! central as `Event::Joystick([AxisEvent { axis: X, .. }, AxisEvent { axis:
//! Y, .. }, ..])` — structurally identical to events produced by the
//! central's own PMW3610 device. Both land on the same `EVENT_CHANNEL` and
//! flow through the same processor chain, with no source tag.
//!
//! The trick: wrap the central-local device with [`AxisRelabel`] so its
//! Joystick events go out tagged with `Axis::H` / `Axis::V` instead of
//! `Axis::X` / `Axis::Y`. Peripheral events still arrive with X/Y. The
//! processor chain is
//! `[PeriphScrollRelabel, ScrollProcessor, PointerProcessor]`:
//!
//! * [`PeriphScrollRelabel`] (while H+J held) rewrites peripheral X/Y → H/V
//! * [`ScrollProcessor`] matches H/V (central-local, or right ball on H+J hold)
//!   → MouseReport wheel
//! * [`PointerProcessor`] matches X/Y (peripheral-forwarded) → MouseReport x/y
//!
//! Each processor returns `Stop` once it matches its axes, so the chain
//! routes deterministically. Releasing H+J clears the hold flag and the
//! right ball returns to pointer mode.

use core::cell::RefCell;
use core::sync::atomic::{AtomicBool, AtomicI32, Ordering};

use embassy_sync::blocking_mutex::raw::CriticalSectionRawMutex;
use embassy_sync::signal::Signal;
use embassy_time::{Duration, Instant, Timer, with_timeout};
use rmk::channel::KEYBOARD_REPORT_CHANNEL;
use rmk::descriptor::WheelMouseReport;
use rmk::event::{Axis, Event};
use rmk::hid::Report;
use rmk::input_device::{InputDevice, InputProcessor, ProcessResult};
use rmk::keymap::KeyMap;
use usbd_hid::descriptor::MouseReport;

use crate::config;

/// One-shot pulse emitted by [`PointerProcessor`] every time the peripheral
/// half forwards a Joystick(X,Y) event. The status-LED controller in
/// `src/status_led.rs` watches this signal and forces the LED to purple for
/// a short hold window, so the user sees the central LED light up while
/// the right-hand trackball is being moved.
pub static PERIPHERAL_ACTIVITY: Signal<CriticalSectionRawMutex, ()> = Signal::new();

/// Diagnostic (round 7, feature `led-ball-diag`): incremented every time
/// [`ScrollProcessor`] actually emits a wheel HID report (the successful
/// `try_send` branch). Read-and-reset by `config::take_scroll_emits()`;
/// non-zero on a poll tick means the firmware emitted fine end-to-end, so a
/// dead scroll with this still flashing points at macOS, not the firmware.
/// Unconditional (cheap atomic add) so it always counts; only its LED
/// consumption is feature-gated.
pub static SCROLL_EMITS: core::sync::atomic::AtomicU32 = core::sync::atomic::AtomicU32::new(0);

// ─── Auto mouse layer ───────────────────────────────────────────────
//
// kobu's keymap reserves layer 4 as the mouse layer (MouseBtn1/2/3 etc.), but
// no key in keyboard.toml ever activates it — so before this it was completely
// unreachable. ZMK-style "auto mouse layer": moving the pointer (the RIGHT /
// peripheral trackball) temporarily switches to the mouse layer so the mouse
// buttons are at your fingertips, and it falls back to the previous layer after
// a short idle window.
//
// [`PointerProcessor`] pulses [`AUTO_MOUSE_ACTIVITY`] on every real (non-zero)
// pointer motion. [`run_auto_mouse_layer`] (spawned from `src/central.rs`)
// activates [`AUTO_MOUSE_LAYER`] on the first motion and holds it UNBOUNDED
// while the hand is resting/mousing — deactivation happens only on typing
// resume (the instant typing-kill) or once a CLICK completes and neither a
// follow-up press nor ball motion arrives within [`AUTO_MOUSE_CLICK_GRACE`]
// (the click-ends-the-session rule; see the hold branch). Scroll (the LEFT
// ball) does NOT trigger it — you scroll on the base layer while typing, so
// hijacking the layer on scroll would be surprising.

/// Pulsed on each non-zero peripheral pointer-motion event. Latching `Signal`,
/// so a pulse raised while [`run_auto_mouse_layer`] is mid-iteration is
/// remembered and the next `wait()` returns immediately — no motion edge is
/// lost and a fast flurry of samples collapses to "still moving".
static AUTO_MOUSE_ACTIVITY: Signal<CriticalSectionRawMutex, ()> = Signal::new();

/// Pulsed on every EMITTED pointer report (real cursor motion), including
/// slow/small mousing where the raw sensor sample was sub-count (x=y=0) and so
/// never pulsed [`AUTO_MOUSE_ACTIVITY`] — yet `pend_*` still periodically crosses
/// a full count and emits a report, so the cursor visibly moves. Historically
/// the HOLD branch's idle timer was re-armed by EITHER signal (the "マウスは動く
/// のにレイヤーが消える" fix); with the idle timeout now removed the hold branch
/// only DRAINS both signals so a stale latched pulse can't instantly re-activate
/// the layer right after the typing-kill. It feeds the HOLD only, never
/// ACTIVATION, so it can't switch layer 4 on during typing.
static AUTO_MOUSE_KEEPALIVE: Signal<CriticalSectionRawMutex, ()> = Signal::new();

/// Gross pointer travel (Σ|dx|+|dy| in raw 800-CPI counts) banked by
/// [`PointerProcessor`] since the last time [`run_auto_mouse_layer`] inspected
/// it. Separate from `POINTER_ACCUM_*` (which `run_pointer_flush` zeroes on its
/// own cadence) so the activation gate can read travel without racing the flush.
/// A typing wobble is small and decays between bursts so it never reaches the
/// threshold; one deliberate flick blows past it.
static AUTO_MOUSE_TRAVEL: AtomicI32 = AtomicI32::new(0);

/// Layer activated while the pointer is moving. Matches keyboard.toml layer 4
/// (the mouse layer). `NUM_LAYER` is 8, so this is always in range; if it ever
/// isn't, `activate_layer` warns and no-ops rather than panicking.
const AUTO_MOUSE_LAYER: u8 = 4;

/// True while [`run_auto_mouse_layer`] holds the mouse layer active. Read by
/// `src/status_led.rs`: rmk's `ControllerEvent::Layer` only carries the
/// HIGHEST active layer, so while the Linux toggle layer (7) is latched every
/// event reads "7" and the LED would mask the purple mouse indication without
/// this side channel (2026-08-26, 「winとlinuxモードのledの色がおかしい」fix).
pub static AUTO_MOUSE_LED_ACTIVE: AtomicBool = AtomicBool::new(false);
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

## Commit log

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2026-05-05 fix(pcb/thumb-unit-right): GND pour, mirror PMW3610, swap to roBa XIAO footprint
    - Schematic: switch U1 footprint from mcu:xiao-ble-tht to
    mcu_roba:XIAO_nRF52840_wBAT_wNFC_1 so back-side BAT_SW / NCS / COL4
    pads are exposed; tie XIAO 5V (pin 14) to no_connect since the
    battery path goes through SW1 → BAT_SW instead.
    - PCB: align U2 (PMW3610) to (175.770, 103.150) so it mirrors the
    left half exactly (same XY, opposite layer), enabling a single
    trackball housing STL to be reused mirrored.
    - PCB: add F.Cu GND zone covering the SMD side; clean up routing so
    every GND/+3V3/+1V8/SPI/matrix net resolves with zero unconnected
    pads.
    DRC: 0 unconnected, 0 schematic-parity errors. Rema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
    [thumb-unit-right.kicad_pcb, thumb-unit-right.kicad_sch]
2026-05-05 fix(pcb/thumb-unit-left): GND pour, swap to roBa XIAO footprint, clean routing
    - Schematic: switch U1 footprint to mcu_roba:XIAO_nRF52840_wBAT_wNFC_1
    to match the right half (same schematic file structure; the two
    halves only differ in PCB).
    - PCB: add B.Cu GND zone (SMD side for the left half is the bottom
    layer) and remove F.Cu↔B.Cu stitching vias that were blocking the
    zone from reaching C2 / J1 / U3 GND pads.
    - PCB: route +3V3, +1V8, the SPI bus (SDIO/SCLK/MOTION/NCS), the
    keyboard matrix (ROW0-3 × COL0-4), the trackball charge-pump and
    VCSEL nets, and the BAT_SW power switch path so all nets resolve.
    DRC: 0 unconnected, 0 schematic-parity errors. Remaining warnings are
    i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
    [thumb-unit-left.kicad_pcb, thumb-unit-left.kicad_sch]
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2026-05-10 refactor(firmware): clean up central run loop with nested join
    Replace the pending() placeholders with a `join(join4(...), ...)` shape
    that exactly matches the five concurrent futures we need (matrix scan,
    keyboard report processor, run_peripheral_manager, run_rmk, scan_peripherals).
    No behavior change.
    [central.rs]
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2026-05-10 fix(firmware): replace BidirectionalMatrix with hand-rolled MixedDiodeMatrix
    The BidirectionalMatrix-based build registered zero keys on the user's
    hardware even after a clean flash_nuke. Suspect causes are the
    per-cell pin direction flips combined with a row/col indexing quirk
    in BidirectionalMatrix's resume-from-scan_pos branch. Rather than
    debug the upstream type, replace it with a small custom InputDevice
    that does two clean scan passes per cycle:
    Pass A — main keys (rows 0..2, all 5 cols), col2row direction.
    Drive col_pins[c] HIGH, read row_pins[0..2]. Works for the
    reversed main-unit diodes (anode physically on /COL).
    Pass B — thumb keys (row 3 only), row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
    [central.rs]
2026-05-10 fix(firmware): use default StorageConfig (num_sectors=2) instead of 6
    The hand-rolled main was using StorageConfig { start_addr: 0,
    num_sectors: 6, .. } which on the Adafruit-bootloader-shipped XIAO
    nRF52840 reaches into the bootloader region from the top of the FLASH
    window declared in memory.x. The runtime nrf-mpsl Flash driver routes
    writes through the SoftDevice timeslot and was apparently hanging on
    the storage init step (which is awaited *before* run_rmk's USB-HID
    setup), leaving the chip running but never enumerating as USB HID.
    User reported "central_test.uf2 → LED on but USB device tree shows
    no kobitokey entry" which is exactly the symptom of run_rmk never
    starting.
    Match the m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
    [central.rs]
2026-05-10 revert(firmware): drop hand-rolled BidirectionalMatrix / MixedDiodeMatrix attempts
    The hand-rolled mains never enumerated USB. Confirmed by user:
    LED came on but the USB device tree showed no kobitokey entry, while
    the macro builds always enumerate. Multiple iterations over the
    suspected causes (scan-map indexing in BidirectionalMatrix, Flex pin
    init, storage_config sector count) did not isolate the difference.
    The macro path is doing something during chip / behavior / split
    init that the hand-rolled variant is missing, and bisecting that
    without RTT or USB-CDC defmt is too slow to keep the keyboard down.
    Roll back to the macro form for both halves so we can ship a working
    firmware again. E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
    [central.rs]
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2026-05-13 feat(firmware): map LEFT trackball to scroll wheel
    Adds a `ScrollProcessor` (`src/scroll_processor.rs`) that converts
    PMW3610 Joystick events into `MouseReport` wheel deltas instead of
    pointer motion. Both axes are summed and negated into the vertical
    wheel (`wheel = -(x + y)`, `pan = 0`) so that rolling the ball in
    any direction produces a vertical scroll, with rightward roll
    mapping to scroll-down per the desired ergonomics.
    `central.rs` uses `#[Overwritten(entry)]` to swap the
    macro-generated default `Pmw3610Processor` out of the
    `run_processor_chain!` and drop in `ScrollProcessor` instead. All
    other generated bindings (matrix, keyboard, keymap, storage, BLE
    stack, USB driver, peripheral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
    [central.rs]
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2026-05-15 feat(firmware): show battery level on central RGB LED
    Wires the XIAO nRF52840's onboard SAADC battery reading (AIN7_BAT /
    P0.31, fed by the on-module 1M/1M divider) into RMK's `BatteryProcessor`
    and adds a new `BatteryLedController` (`src/battery_led.rs`) that
    subscribes to `CONTROLLER_CHANNEL` and drives the onboard RGB LED to
    one of three colors based on the percentage:
    * > 60% → green (G on, R/B off)
    * 20–60% → yellow (R + G on, B off)
    * ≤ 20% → red (R on, G/B off)
    The LED is common-anode: pin LOW = on. On the central half the macro
    no longer declares P0.30 as a static output; instead `central.rs`
    claims P0.26 (R), P0.30 (G), and P0.06 (B) inside a
    `#[controller(eve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
    [central.rs]
2026-05-15 feat(firmware): flash central LED purple on peripheral trackball activity
    Hooks the existing peripheral→central Joystick(X,Y) forward path: every
    time `PointerProcessor` (which by axis label only ever matches events
    forwarded from the RIGHT half) emits a MouseReport, it also pulses a
    new `PERIPHERAL_ACTIVITY` Signal in `src/trackball.rs`. The status LED
    controller listens for that pulse and forces the RGB LED to purple
    (R + B, G off) for 200 ms, after which it falls back to the battery
    color.
    The old `BatteryLedController` (`src/battery_led.rs`) is replaced by a
    unified `StatusLedController` (`src/status_led.rs`) that owns the
    R/G/B GPIOs and merges both inputs:
    * `ControllerEvent::Bat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
    [central.rs, status_led.rs, trackball.rs]
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2026-05-15 chore: merge kobu-config into web/ as a monorepo subdirectory (#42)
    * Squashed 'web/' content from commit 7dc58ec
    git-subtree-dir: web
    git-subtree-split: 7dc58ece8db228da6163cd86af7e335ebad0746b
    * chore: merge kobu-config into web/ as a monorepo subdirectory
    Brings the kobu-config web app (previously a separate
    s-katada/kobu-config repository) into this monorepo under web/. The
    history is preserved as a squashed subtree merge so all the
    Phase 0-2 commits remain navigable from `git log -- web/`.
    Why move it:
    * kobu firmware and kobu-config web are tightly coupled — the Vial
    keyboard UID, customKeycodes labels, ble_profiles_num count, and
    the matrix layout all need to stay in sync. S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
    [pnpm-lock.yaml]
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2026-05-17 fix(firmware): make kobu discoverable in macOS Bluetooth settings
    Enable XIAO DCDC and stronger BLE TX, and patch RMK 0.8.2 at build time
    to advertise on LE 1M and default to BLE-priority when no preference is
    stored (RMK #157/#159).
    [build.rs]
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2026-05-21 feat(web): add Cloudflare Workers setup with /__release proxy
    Serves the Vite-built SPA via the ASSETS binding with SPA fallback,
    and routes /__release/* to github.com server-side so uf2 firmware
    downloads aren't blocked by CORS in production (matches the dev
    server proxy in vite.config.ts).
    Adds wrangler + @cloudflare/workers-types, cf:dev / cf:deploy /
    cf:tail npm scripts, a worker tsconfig, biome coverage for worker/,
    and .wrangler/.dev.vars gitignore entries.
    [pnpm-lock.yaml]
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2026-05-22 chore(case): split STL exports into main-unit/, thumb/, common/
    Avoid the bare `main/` directory name in favor of `main-unit/`, which
    matches the existing main-unit-*-spacer-* file prefixes and the pcb/
    layout (main-unit-left/, main-unit-right/).
    oyayubi-side-plate and track-ball-case live under thumb/ because they
    are physically part of the thumb cluster. hinji-coveor and xiao-cover
    sit in common/ since they are shared / inter-unit pieces with no
    left/right variant.
    [hinji-coveor.stl, main-bottom-plate.stl, main-side-plate.stl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]
2026-05-22 chore(case): move xiao-cover to thumb/, fix hinji-coveor typo
    xiao-cover belongs with the thumb-cluster STLs (correction to
    a3c4f64). Also rename hinji-coveor.stl → hinji-cover.stl to fix
    the lingering "coveor" typo.
    [hinji-cover.stl, xiao-cover.stl]
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2026-05-23 feat(firmware): introduce kobu_config atomic-singleton plane (#39) (#52)
    Lays the groundwork for the kobu-specific Vial Custom* command set
    from issue #39. Pure refactor — defaults preserve today's behaviour
    byte-for-byte; only the hot-path read sites change.
    ### New
    - `firmware/src/config.rs` — `KobuSettings` data model matching the
    wire IDs in issue #39 (trackball_cpi / scroll_throttle_ms /
    scroll_invert_{x,y} / status_led_purple_hold_ms /
    status_led_battery_{high,low}_threshold). Each field has a
    matching `Atomic*` singleton with `apply()` / `snapshot()` for the
    future control-plane handler.
    - Read helpers (`status_led_battery_high_threshold()` etc.) so
    consumers don't ha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
    [central.rs, status_led.rs, trackball.rs]
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2026-05-23 feat(web): auto bootloader-jump for central install (no RESET button) (#56)
    * feat(case): add thumb power-switch STL, refresh thumb-side-plate and xiao-cover
    * feat(web): auto bootloader-jump for central install (no RESET button)
    Eliminates the physical RESET 2-tap on central firmware installs when
    the kobu is already connected via WebHID.
    ### What changes for the user
    Before:
    Click "セントラルをインストール" → "RESET ボタンを素早く 2 回押す" →
    wait for XIAO-BOOT to mount → file picker → write.
    After (central + connected):
    Click "セントラルをインストール" → "ブート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
    [power-switch.stl, thumb-side-plate.stl, xiao-cover.stl]
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2026-05-23 chore(case): drop oyayubi-side-plate, refresh thumb-side-plate and xiao-cover
    oyayubi-side-plate (親指サイドプレート) duplicated thumb-side-plate;
    keep only the latter to avoid two names for the same part.
    [oyayubi-side-plate.stl, thumb-side-plate.stl, xiao-cover.stl]
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2026-05-25 feat(firmware): patch RMK 0.8 for reliable BAS reporting on macOS
    Adds three build.rs patches to crates.io rmk-0.8.2 / rmk-macro-0.7.1
    sources so the BLE Battery Service surfaces in the macOS Bluetooth
    menu reliably:
    * patch_rmk_battery_service: replaces BleBatteryServer::run with a
    kobu-specific loop that (1) drops the upstream 30-second
    first-report window, (2) sends a non-zero sentinel on connect so
    macOS doesn't latch onto the trouble_host default 0%, (3) skips
    the "keypress in last 60s" gate so reports flow on an idle
    keyboard, and (4) heartbeats the last known value every 60s.
    * patch_rmk_battery_processor_signal: drops the "only signal when
    the percent changes" guard so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
    [build.rs]
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2026-05-27 feat(firmware): live kobu settings over Vial + smooth wireless trackball
    Wire RMK 0.8's Vial Custom Value channel (0xC0) so kobu-config can read
    and write runtime settings instead of warn-and-drop:
    - build.rs patches CustomGetValue/CustomSetValue/CustomSave for ids
    0x01..0x07 (trackball CPI multiplier, scroll throttle/invert, status
    LED purple hold + battery thresholds) backed by atomics injected into
    rmk::input_device::battery; CustomSave acks silently for 0xC0.
    - config.rs becomes a thin facade delegating to those atomics, so the
    scroll / status-LED hot paths see host writes live.
    Fix the "fully-wireless trackball feels laggy / のっぺり / もっさり" problem.
    The peripheral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
    [battery_source.rs, build.rs, central.rs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]
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2026-05-31 feat(firmware): auto mouse layer (activate layer 4 on trackball motion)
    Layer 4 (the mouse layer with MouseBtn1/2/3) had no key activating it, so
    it was unreachable. Add a ZMK-style auto mouse layer: moving the right
    (peripheral) trackball activates layer 4; it deactivates after ~700ms of
    no pointer motion.
    - build.rs: patch RMK 0.8.2 to expose KeyMap::activate_layer /
    deactivate_layer as `pub` so the firmware can drive them.
    - src/trackball.rs: AUTO_MOUSE_ACTIVITY signal pulsed on real pointer
    motion; run_auto_mouse_layer task (de)activates layer 4.
    - src/central.rs: spawn run_auto_mouse_layer in the task join.
    Require-prior-idle (typing false-trigger fix): typing vibration jostles
    th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
    [build.rs, central.rs, trackball.rs]
2026-06-01 feat(case): split thumb XIAO cover into left/right variants
    Replace the single xiao-cover.stl with mirror-specific xiao-cover-left.stl
    and xiao-cover-right.stl so each thumb unit gets its correctly-handed cover.
    [xiao-cover-left.stl, xiao-cover-right.stl, xiao-cover.stl]
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2026-06-01 fix(firmware): resolve boot-trackball BLE wedge + trackball UX
    The long-standing wedge: rolling the trackball before the Mac BLE connection
    completes froze the whole keyboard. Root cause (rounds 5-10): on a bonded
    STALE resume (kobu's slide switch cuts power with no BLE terminate, so the Mac
    holds the link until its supervision timeout) the Mac fast-re-encrypts and
    fires a dense GATT cache-revalidation burst; kobu opened the trackball pipeline
    on the first encrypted read — straight into that burst, before host TX credits
    were flowing. The ~500Hz pointer flood then starved the single shared trouBLE
    TX queue + packet pool that BOTH the host and split links multiplex through on
    one radio; the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
    [build.rs, central.rs, trackball.rs]
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2026-06-02 fix(firmware/trackball): inline pointer emit + auto-mouse keep-alive + click-shake guard
    - PointerProcessor emits the MouseReport inline like ScrollProcessor
    (1-in-flight via len()==0); removed the run_pointer_flush drain task,
    its POINTER_ACCUM/POINTER_PENDING statics and the 4ms tick, and
    rebalanced the central.rs task join. Cuts the pointer-only baseline lag.
    - Auto-mouse layer: keep-alive on every arriving sample (not only on a
    successful send) + hold 250→400ms, so layer 4 no longer drops while
    mousing slowly ("マウスは動くのにレイヤーが消える").
    - Click-shake: 40ms motion-freeze on a button-press edge + a 2-count
    held-button deadzone — kills misclick jitt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
    [central.rs, trackball.rs]
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2026-06-02 fix(firmware/trackball): auto-mouse activates on gentle ball motion
    Slow/gentle trackball motion never activated the auto-mouse layer (layer
    4), so the purple LED never lit and the layer-4 mouse buttons were
    unreachable. Root cause: the activation travel gate required 80 raw
    counts, banked only on non-zero samples, but the 60ms decay zeroed the
    bank between the sparse non-zero samples a slow roll produces (the
    sub-count polls return x=y=0 while the cursor still creeps via the pend_*
    carry) — so it could never sum to 80.
    Loosen the gate so a light touch-and-roll activates: travel threshold
    80 -> 1, decay window 60ms -> 160ms. Typing false-triggers stay blocked
    by the independent AUTO_MOUSE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
    [trackball.rs]
2026-06-02 fix(firmware/trackball): drop auto-mouse hold timeout 400ms -> 140ms
    The mouse layer lingered too long after the ball stopped, so going back
    to typing right after mousing could still land on layer 4. Cut the HOLD
    timeout hard from 400ms to 140ms so the layer releases promptly on a real
    pause. Continuous/slow mousing still holds it — the per-sample
    AUTO_MOUSE_KEEPALIVE refreshes the window every ~8ms, far under 140ms.
    Re-activation is unchanged (AUTO_MOUSE_PRIOR_IDLE 300ms + travel gate).
    Note: a mouse-button press does not refresh the hold window (only ball
    motion does), so a >140ms pause before clicking can drop the layer first.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
    [trackball.rs]
2026-06-02 fix(firmware/trackball): set auto-mouse hold timeout to 150ms
    Follow-up to the 400->140ms cut: user settled on 150ms for the hold
    window after the ball stops. Activation threshold stays at 1 (minimum) —
    the layer engages on the lightest touch-and-roll already.
    [trackball.rs]
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2026-06-03 feat(firmware/zmk/trackball): vendor PMW3610 driver; poll + flaky-SPI fixes
    kobu's LEFT scroll trackball would not work under stock ZMK. Root-caused on
    hardware (USB-CDC logging) to two kobu-specific issues that KobitoKey (same
    badjeff driver, cleaner PCB) does not hit:
    1. The badjeff driver is interrupt-only, but kobu's MOTION/P0_28 line never
    reliably drives the IRQ. Vendor the driver in-repo and add an
    IRQ-independent SPI poll (CONFIG_PMW3610_POLL_INTERVAL_MS, 10 ms).
    2. kobu's LEFT 3-wire SDIO read is marginal: it intermittently returns 0xFF
    garbage, which (a) fails the product-id/self-test init step and (b) decodes
    to nonzero deltas -> phantom ("runaway") scroll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
    [pmw3610.c]
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2026-06-03 fix(firmware/zmk/trackball): reject glitch-spike deltas (gyun scroll)
    Rolling the LEFT scroll ball slowly sometimes produced a sudden large "gyun"
    jump (usually up). Root cause: a PARTIAL flaky-SPI read — buf[0] is valid (so
    the buf[0]==0xFF garbage gate misses it) but the XY_H byte is corrupted, so a
    single sign-nibble flip decodes to a ±256..±2048 delta. The un-clamped
    zip_scroll_scaler (÷30) then emits ~68 wheel units in one event.
    Add CONFIG_PMW3610_MAX_DELTA: zero any decoded per-sample delta whose magnitude
    exceeds it. A real hand-roll never exceeds 90 counts/sample (matches RMK's
    ScrollProcessor SCROLL_MAX_UNITS=3 × SCROLL_STEP=30 = ±90 cap; fast flicks stay
    under it). Enabled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
    [pmw3610.c]
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2026-06-04 feat(firmware/zmk/pmw3610): force-awake heartbeat to fix scroll startup latency
    The LEFT (scroll) sensor runs pure-IRQ (POLL_INTERVAL_MS=0) to preserve
    slow-roll sub-count accumulation, but that means the one-shot force-awake
    init write is never retried; a flaky 3-wire SDIO miss then leaves the
    sensor dozing in a REST mode (40-500ms sample interval), so scrolling
    "takes a moment to start". The existing re-assert only runs in the poll
    callback (disabled here) and on activity-state changes (not periodic).
    Add CONFIG_PMW3610_FORCE_AWAKE_HEARTBEAT_MS: a standalone delayable work
    that re-asserts the performance (RUN) register every N ms WITHOUT reading
    the motion burst — so, unlike polling, it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
    [pmw3610.c]
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2026-06-07 fix(firmware/zmk): LEFT scroll — pure-IRQ + decoupled force-awake re-assert (slow-roll freeze) [HW-UNVERIFIED]
    Follow-up to 90c3177 (250ms watchdog), which still froze on slow rolls. Deeper
    root-cause analysis (vs the proven KobitoKey c241b53 driver) found TWO bugs:
    1. PURGE RACE (the slow-motion freeze): report_data keeps function-static
    dx/dy/last_smp_time with a REPORT_INTERVAL_MIN(8ms) purge. The kobu-only
    250ms poll ALSO calls report_data, and 250ms >> 8ms trips the purge on every
    tick, zeroing partially-accumulated slow-roll counts before they emit. Fast
    rolls cross threshold within one sub-8ms IRQ burst → immune. = "ゆっくり動かすと固まる".
    (Also why the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
    [pmw3610.c]
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2026-06-08 feat(firmware/rmk): i16 mouse report + smart conn re-assert + tap-preferred hold-tap
    From the pointer/keyboard latency investigation: (1) widen the BLE mouse HID report X/Y i8->i16 (ZMK parity) via build.rs rmk patches + emit WheelMouseReport (trackball.rs), removing the host_rate*127 cursor-speed ceiling behind pointer under-travel (changing the report map needs a macOS re-pair); (2) trackball.rs motion-gated, 2s-cooldown host conn-param re-assert to re-tighten a power-relaxed link without periodic churn; (3) keyboard.toml FH hold-tap -> tap-preferred (hold_on_other_press=false, 350->200ms) to curb split-jitter tap->hold mis-fires.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
    [build.rs, trackball.rs]
2026-06-10 fix(firmware/rmk): port in-registry r25 host-conn-refresh patch into build.rs
    The smart conn re-assert consumer loop (KOBU_HOST_CONN_DRIFT -> request
    [7.5,15]ms when interval >12ms) existed ONLY as an uncommitted hand patch in
    the cargo registry checkout (marker 'r25 pointer-triggered host conn refresh
    v2 applied'). The committed build.rs left the loop at r24's inert >4s gate, so
    any cargo clean -p rmk / fresh-registry / CI build silently shipped a binary
    where the re-assert never acts. patch_rmk_host_conn_refresh_r25() reproduces
    the registry state byte-identically on a fresh extraction and no-ops (marker)
    on the current one. No behavior change on an already-patched registry.
    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
    [build.rs]
2026-06-10 fix(firmware/rmk): scroll-side smart conn re-assert — left ball recovers a relaxed link itself (S2)
    Root cause of 'left ball dead until the right ball moves': macOS power-relaxes
    the bonded host link (~15ms -> 30-50ms) after an idle spell, and the ONLY
    KOBU_HOST_CONN_DRIFT trigger lived in PointerProcessor (right/peripheral ball,
    X/Y events). ScrollProcessor (left/central ball, H/V via AxisRelabel) had no
    trigger, so a scroll-only phase stayed relaxed indefinitely and every wheel
    tick felt dead/laggy until the pointer moved. Mirror the identical
    threshold(18ms)+cooldown(2s) re-assert block into ScrollProcessor, fired per
    arriving H/V sample before the units==0/throttle early-returns so eve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
    [trackball.rs]
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2026-06-10 feat(firmware/rmk): scroll feel — idle decay + direction-flip reset + fold V axis into wheel
    Three deterministic left-ball dead zones removed (independent of link health):
    1. V axis was fully discarded ('let _ = vertical') — a vertical-ish roll
    produced zero scroll forever. Port the HW-validated ZMK mapping
    (kobu_left.overlay, 2026-06-06): both axes fold into the vertical wheel,
    input = h + (-vertical); roll-up = scroll-up, roll-right = scroll-up.
    Same accepted trade-off as ZMK: the up+left / down+right diagonal cancels.
    If vertical feels reversed on HW, flip the one negation (see comment).
    2. No idle decay: up to 29 stale counts from minutes ago pre-loaded (or
    fought)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
    [trackball.rs]
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2026-06-11 fix(firmware/rmk): split-link CE length extension — drain >> pointer sample rate [HW test pending]
    The split link's ConnectParams inherited trouble's default min/max_event_length
    = 0, so the nrf-sdc reserves only a minimal slot per 7.5ms connection event
    (~1 PDU ≈ 133 PDU/s drain) against the right ball's 125 samples/s production —
    a 6% margin on a radio the central timeshares with the 15ms Mac host link.
    Scheduling collisions tip drain below production; the pipeline queues fill (the
    sensor keeps accumulating losslessly), and the cursor trails the hand by the
    queued backlog: the sustained-motion 追従遅延 that recovers after a short
    idle, identical on BLE and USB (host transport is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
    [build.rs]
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
